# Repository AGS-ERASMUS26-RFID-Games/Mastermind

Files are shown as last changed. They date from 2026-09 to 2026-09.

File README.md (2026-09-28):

# RFID Games – Documentation

Arduino Mega 2560 project with two games, *Mastermind* and the
*Color Memory Game*, on the same hardware: four RFID readers, a 16×16 LED
matrix and three buttons.

This file describes the game selection, both game principles, the settings,
the display, the structure of the code and the wiring (section 7). Both
games are in one sketch, `rfid_games.ino`. The complete schematic is
`mastermind.kicad_sch` (KiCad 7); it did not change for the second game.

---

## 1. Game selection

| Button | Pin | Function |
|---|---|---|
| Button 1 | D2 | start a game, confirm an input |
| Button 2 | D3 | select **Mastermind**; hold 3 s = quit the running game |
| Button 3 | D18 | select **Color Memory Game**; hold 3 s = quit the running game |

- After switching on, **Mastermind** is selected and its start screen appears.
- Button 2 and button 3 work on every **start screen** and every **end
  screen** (win, lose, game over). They show the start screen of the
  selected game. Button 1 then starts it.
- During a **running game**, a short press of button 2 or button 3 is
  ignored, so an accidental press never ends a game. The press is discarded
  and does not act later either.
- **Quitting a running game:** hold button 2 or button 3 for 3 s
  (`ABORT_HOLD_TIME`). The game ends immediately and the start screen of
  the selected game appears – button 2 → Mastermind, button 3 → Color
  Memory Game. There is no progress display; after 3 s the start screen
  simply appears. Releasing earlier cancels the hold, the game continues.
  This works in every phase of a running game, also while the Color Memory
  sequence is shown.
- A button that is already held down when a game starts does not quit the
  new game; it has to be released and pressed again first. The same
  applies after quitting: the button still held does not count twice.
- On an end screen, button 1 starts a new game of the **same** game
  directly.

---

## 2. Mastermind

At the start of a game, the Arduino rolls a secret sequence of four colors.
The choices are **Red, Green, Blue and Yellow**; each color may appear more
than once. The player tries to guess this sequence.

### Course of a round

1. **Input:** A color chip is placed on each of the four readers. The
   corresponding LED in the current row shows the color of the chip. If no
   chip (or an unknown chip) is present, the LED lights up white.
2. **Confirm:** As soon as a known chip lies on all four readers, the row
   **blinks**. Pressing button 1 confirms the input. With the chip lock
   active, all readers are checked once more first; if the result differs
   from the display, the press is ignored and the corrected row is shown
   (see "Chip lock").
3. **Evaluate:** To the right of the input, the result appears as four LEDs:
   - **Green** = right color in the right position
   - **Yellow** = right color, but in the wrong position
   - **Red** = no hit for this chip: its color does not appear in the
     sequence, or all chips of this color in the sequence are already
     matched by other hits (see the duplicate rule below)

   The evaluation is **not position-based**: all green LEDs light up first,
   then all yellow ones, then the red ones. So the order does *not*
   reveal which position is correct – exactly like real Mastermind.
4. **Continue:** The next attempt is entered in the row below.

### Winning and losing

- **Won:** All four evaluation LEDs are green (color *and* position correct
  everywhere).
- **Lost:** The maximum number of attempts (`MM_MAX_ATTEMPTS`) is reached
  without the sequence being guessed.

In both cases a final screen appears (see section 5), after which a new game
starts at the press of button 1.

### Evaluation – an example

Secret sequence: **Red · Red · Green · Blue**

| Input | Green | Yellow | Red | Explanation |
|---|---|---|---|---|
| Red · Green · Green · Blue | 3 | 0 | 1 | Positions 1, 3, 4 match; the second green is one too many |
| Red · Blue · Blue · Red | 1 | 1 | 2 | Position 1 matches (green); another Red exists in the sequence but is misplaced (yellow) |
| Yellow · Yellow · Yellow · Yellow | 0 | 0 | 4 | Yellow does not appear in the sequence at all |

Important is the rule for duplicate colors: Each chip of the secret sequence
can produce only **one** hit. A second Red in the input only turns yellow if
the secret sequence also contains a second (not yet matched) Red.

---

## 3. Color Memory Game

The player has to remember a random color sequence and rebuild it with the
chips. The sequence gets one color longer with every successful round.

### Course of a round

1. **New sequence:** At the beginning of every round the Arduino generates a
   **completely new** random sequence of the colors Red, Green, Blue and
   Yellow. The previous sequence is not extended. Round 1 has 1 color,
   round 2 has 2 colors, and so on up to `CM_MAX_LENGTH` (20). After that,
   every round has 20 colors – the game continues endlessly until a mistake
   is made.
2. **Display:** After a short dark pause, the **whole sequence is shown at
   once** on a grid (see section 5). The display time grows with the
   length: `CM_SHOW_TIME_BASE` + `CM_SHOW_TIME_PER_COLOR` per color
   (default 1.5 s for 1 color, 11 s for 20 colors). Then every used grid
   place turns white: the player sees how many colors are needed, but no
   longer which ones.
3. **Input in blocks:** Because there are only four readers, the sequence is
   entered in blocks of four – one block per grid row. Reader 1 to 4
   correspond to position 1 to 4 of the current row. The last block only
   needs as many readers as colors are left (e.g. 2 readers for a sequence
   of 6). The readers that are not needed are **not read at all** and can
   never get a chip (see "Active readers" in section 4). A chip placed on
   them is ignored.
   - The current row shows the chips live, exactly as in Mastermind (no /
     unknown chip → white).
   - When a known chip lies on every required reader, the row **blinks** and
     button 1 confirms the block. With the chip lock active, the readers are
     checked once more first (see "Chip lock").
   - The confirmed block stays visible on the grid in its colors.
4. **Remove the chips:** Before the next block can be confirmed, the chips
   have to be removed from the required readers. As long as chips of the
   last block are still lying there, the next row stays **white** (it does
   not show the chip colors and does not blink), and button 1 is ignored.
   Only when all required readers were empty does the row show the chips
   live again. This also applies to the first block of a round: chips still
   lying there from the previous round are not shown. This makes it possible to use the same
   chips several times in one sequence (e.g. Red – Blue – Red – Red – Red)
   and prevents a double press from confirming the same block twice.
5. **Evaluate:** Only when the complete sequence has been entered does the
   Arduino compare it with the generated sequence, **position by
   position**. Directly below every color an LED appears:
   - **Green** = correct color at this position → **1 point**
   - **Red** = wrong color at this position
6. **Continue:** If every position is correct, the next round starts with a
   new sequence that is one color longer. If at least one position is
   wrong, the game is over.

### Evaluation – an example

Generated sequence: **Red · Blue · Yellow · Green**

| Position | Sequence | Input | Result |
|---|---|---|---|
| 1 | Red | Red | Green LED, +1 point |
| 2 | Blue | Blue | Green LED, +1 point |
| 3 | Yellow | Green | Red LED |
| 4 | Green | Green | Green LED, +1 point |

Position 3 is wrong, so the game ends after this evaluation.

### Scoring

The score is the number of correct positions **over all rounds of a game**.
Correct positions of the last, failed round count as well.

Example: rounds 1 to 3 without a mistake, then 2 of 4 positions correct in
round 4 → score = 1 + 2 + 3 + 2 = **8**.

### Game over

The end screen alternates between the scrolling text “GAME OVER” in red and
the score as a green number (section 5). Button 1 starts a new game in
round 1 with score 0; button 2 or 3 switches the game.

---

## 4. Operation and important constants

All settings are grouped together at the top of the sketch under *Settings*
and *Pins*: first the Mastermind settings (prefix `MM_`), then the Color
Memory Game settings (prefix `CM_`), then the settings both games share.

### Mastermind

| Constant | Default | Meaning |
|---|---|---|
| `MM_DEBUG_SHOW_SOLUTION` | `true` (test setting) | `true` = show the secret sequence in row 16 during the game (for testing). Set to `false` for normal play. |
| `MM_MAX_ATTEMPTS` | `1` (test setting) | Number of attempts, after which the game is lost. Allowed are **1–15** (row 16 is reserved for the debug solution). An invalid value produces a clear error message at compile time. Use e.g. `10` for normal play. |

### Color Memory Game

| Constant | Default | Meaning |
|---|---|---|
| `CM_MAX_LENGTH` | `20` | Maximum length of the sequence. Allowed are **1–20** (the grid has 5 rows × 4 positions), checked at compile time. After reaching it, every round has this length. |
| `CM_SHOW_PAUSE` | `300` ms | Dark pause before the sequence appears |
| `CM_SHOW_TIME_BASE` | `1000` ms | Display time of the sequence … |
| `CM_SHOW_TIME_PER_COLOR` | `500` ms | … plus this much per color |

### Shared

| Constant | Default | Meaning |
|---|---|---|
| `DEBUG` | `1` | `1` = serial output on (UIDs, solution, evaluation), `0` = off (saves a little memory) |
| `BRIGHTNESS` | `4` | Brightness of the matrix (0–255) |
| `BLINK_INTERVAL` | `250` ms | Blink rate of a complete input |
| `SCROLL_INTERVAL` | `70` ms | Speed of the scrolling texts (smaller = faster) |
| `END_IMAGE_DURATION` | `4000` ms | Dwell time of the end image before the scrolling text runs again |
| `RESULT_PAUSE` | `1500` ms | Leave the last evaluation on screen before the next screen (end screen resp. next round) appears |
| `DEBOUNCE_TIME` | `30` ms | Debounce of the buttons |
| `ABORT_HOLD_TIME` | `3000` ms | Hold button 2 / 3 this long to quit a running game |

The RFID timing values (`MAX_FAILED_READS`, `POLL_INTERVAL`,
`ANTENNA_WAIT`) come from the original reader sketch and are unchanged. If
chips are detected unreliably, increase `ANTENNA_WAIT` first.

### Range of the readers: gain and transmitter power

The four readers lie only about **3 mm** apart. In addition, some readers
do not lie completely flat, because the pins on their back lift them up on
one side. A tilted reader has a different distance to the chip than its
neighbors, and its field reaches further to one side. Both make it easy for
a chip to be detected by a neighboring reader as well.

If a chip is also detected by a neighboring reader, the range of the
readers can be reduced with two settings. Because the modules differ, both
are set **individually for every reader**: each constant is an array with
one entry per reader (reader 1 first).

| Constant | Default | Meaning |
|---|---|---|
| `RFID_GAIN_STEP[]` | `{ 2, 2, 1, 1 }` | Receiver gain per reader, step `0`–`5` |
| `TX_POWER_STEP[]` | `{ 2, 1, 1, 2 }` | Transmitter power per reader, step `1`–`8` |
| `PROBE_GAIN_STEP` | `2` | Gain of all readers during the power test of the chip lock (see [Chip lock](#chip-lock)) |
| `FALLBACK_MIN_GAIN_STEP` | `0` | Lowest gain step for a repeated read after a read error (see [Read errors](#read-errors-reading-again-with-less-gain)) |

All values are checked at compile time: an entry outside its allowed range
stops the compilation with an error message.

`RFID_GAIN_STEP` sets the receiver gain, i.e. how well the reader "hears"
the answer of a chip. The RC522 only knows these six values, there are no
steps in between:

| Step | 0 | 1 | 2 | 3 | 4 | 5 |
|---|---|---|---|---|---|---|
| Gain | 18 dB | 23 dB | 33 dB (library default) | 38 dB | 43 dB | 48 dB |

`TX_POWER_STEP` sets the transmitter power, i.e. the strength of the field
itself. A weaker field means a chip on a neighboring reader is no longer
powered at all, which usually works better than a lower gain. Step 8 is the
library default (full power). The MFRC522 library has no function for this;
the sketch writes the driver conductance registers directly: `CWGsPReg` =
step × 4 and the upper half of `GsNReg` = step (step 8 → `0x20` / `0x8` =
reset values). The field does not drop linearly: neighboring steps may
hardly differ, and below a certain step detection stops abruptly.

How far the range actually drops depends on the module, its antenna and
how flat it lies, so the right combination has to be found by testing. The
default values were determined with the separate test sketch
`rfid_sweep_test.ino` (block "RECOMMENDED SETTINGS" in its output). Repeat
this test after changing the hardware – a module swapped, readers moved,
other chips – and enter the recommended values in `RFID_GAIN_STEP` and
`TX_POWER_STEP`.

For fine-tuning, all values can also be changed at runtime via the Serial
Monitor (`DEBUG 1`, 9600 baud), without uploading the sketch again. This
works in every state of both games. A command consists of the letter, the
reader (`0` = all readers, `1`–`4` = one reader) and the step:

| Input | Effect | Example |
|---|---|---|
| `g<reader><step>` | set gain step `0`–`5` | `g24` = reader 2 → 43 dB, `g01` = all readers → 23 dB |
| `t<reader><step>` | set transmitter power step `1`–`8` | `t38` = reader 3 → step 8, `t02` = all readers → step 2 |
| `?` | show current settings | |

After every change the settings of all readers are printed, together with
the values read back from each reader (gain `0x00`/`0x10`/`0x40`/…,
`CWGsP` = step × 4, `GsN` with the step in the upper digit), the gain used
for the power test and finally the current values in the form of the
constants, e.g.

```
RFID settings:
  Reader 1: gain step 2 (33 dB), TX step 2  | gain 0x40 | CWGsP 0x8 | GsN 0x28
  ...
  Power test: gain step 2 (33 dB) on all readers, TX steps 1..8
  constexpr byte RFID_GAIN_STEP[READER_COUNT] = { 2, 2, 1, 1 };
  constexpr byte TX_POWER_STEP[READER_COUNT]  = { 2, 1, 1, 2 };
```

If a reader shows different register values than expected, it did not
accept the setting. Recommended procedure: for each setting, first check
that chips lying directly on each reader are still detected, then check
that a chip on one reader no longer appears on its neighbors. Copy the two
last lines of the output into the sketch – changes made via serial are lost
after a restart.

### Read errors: reading again with less gain

A typical problem with readers this close together: the own chip lies on
the reader, and at the same time a chip on the neighboring reader answers
weakly. With high gain the reader hears both answers, they overlap and the
answer can no longer be decoded. Without a countermeasure the reader would
report *no* chip – the own chip would disappear as long as the neighbor
chip lies there.

`readReader()` therefore distinguishes between "no chip answers" (timeout,
normal) and "a chip answers, but the answer is garbled" (read error). After
a read error, the reader immediately reads again with less gain, one step
at a time down to `FALLBACK_MIN_GAIN_STEP` (default `0` = 18 dB), until the
read is clean. The weak neighbor chip drops below the receiver threshold
first, while the own chip directly on the antenna is still read. Afterwards
the normal gain of the reader is restored. If no step reads cleanly, the
read with the most chips is used.

With `DEBUG 1` a line is printed only when the state of a reader changes,
e.g. `Reader 2: read error at 33 dB -> clean read at 23 dB`,
`Reader 2: read error, also with less gain` or
`Reader 2: reads normally again`. If a reader frequently needs the fallback,
its normal gain is probably too high.

### Active readers

Only the readers the running game needs at the moment are read. In
Mastermind these are always all four. In the Color Memory Game they are only
the readers of the current block: in round 1 only reader 1, for a sequence
of 6 first readers 1–4, then readers 1–2. `activeReaderCount()` returns this
number; `pollReaders()` skips all readers above it.

An inactive reader therefore can never get a chip, neither by its own read
nor by the chip lock. This matters because an empty reader is exactly the
one that picks up the chip of its neighbor most easily. Example: the last
block has 2 colors, and the chip on reader 2 is also seen by reader 3.
Reader 3 is not read at all, so the chip only appears at reader 2 and
belongs to it immediately – no power test, no tie, no white LED.

If an inactive reader still shows a chip from the previous block, it is
forgotten as soon as the reader becomes inactive. A side effect of skipping
the inactive readers: a round with fewer readers is faster.

One limit remains: if a chip is placed on an unused reader while its
active neighbor is **empty**, the neighbor may pick it up and show its
color, because the unused reader cannot claim the chip any more. Chips on
unused readers should therefore simply be avoided.

### Chip lock

If gain and transmitter power alone do not prevent cross-reading, the chip
lock (`CHIP_LOCK = true`, default) makes sure that every chip is assigned
to exactly one reader. It is used by both games. Each polling round then
runs in three steps:

1. **Read:** every active reader reads *all* chips in its field (up to
   `MAX_CHIPS_PER_READER`, default 3), not just one. This matters because
   with two chips in the field the RC522 selects one by its UID bits, not by
   distance – a reader could otherwise report the neighbor's chip instead of
   its own. The reader wakes all chips (WUPA), reads one, puts it to sleep
   (HALT) and then asks again with REQA, which sleeping chips ignore, until
   no chip answers any more.
2. **Assign:** every chip is assigned to at most one reader, by these rules:
   - *Elimination:* if only one free reader is left for a chip, the chip
     belongs to it and the reader is taken. Example: reader 1 sees A and B,
     reader 2 only B → A can only belong to reader 1, so B belongs to
     reader 2. This solves the common case without any measurement.
   - A chip whose readers are all taken belongs to nobody (it was only
     cross-read).
   - *Power test:* if a chip is still seen by several free readers, the
     transmitter power of each of them is lowered step by step (binary
     search over steps 1–8, 4 reads per reader). The reader that still sees
     the chip at the lowest step is closest and gets it. Because the normal
     settings differ from reader to reader, the power test does **not** use
     them: every reader is measured with the same gain `PROBE_GAIN_STEP`
     (default `2` = 33 dB) over the same range 1–8, so the results of
     different readers can be compared. Afterwards each reader gets its
     normal gain and transmitter power back. The result is remembered for
     `PROBE_CACHE_TIME` (default 3000 ms) as long as the same readers
     compete, so the test does not run in every round.
   - If several chips can only belong to the same reader, it keeps the chip
     it already shows; otherwise the power test decides here as well.
   - *Tie:* if several readers reach the same lowest step, the reader that
     already shows this chip keeps it, so a tie does not make a displayed
     chip vanish. The same applies if several chips on one reader tie: the
     chip the reader already shows stays.
   - *In case of doubt white:* if none of the tied readers shows the chip
     yet, nobody gets it. The affected reader shows white, the row does not
     blink and cannot be confirmed – the player sees the problem and
     straightens the chip.

   The reader that currently shows a chip stays a candidate for it even if
   it missed it in this round, so a single dropout does not hand the chip
   over to a neighbor.
3. **Update:** if a chip now belongs to a different reader than before, it
   is removed from the old reader at once. Otherwise the usual rules apply
   (new chip / swap immediately, removal after `MAX_FAILED_READS` failed
   reads).

Before a press of button 1 is accepted – a Mastermind attempt as well as a
Color Memory block – one more complete round runs with a fresh power test
(no remembered results). Only if nothing changes is the input accepted. A
wrong color can therefore never be confirmed.

With `DEBUG 1` every power test is printed, e.g.
`Chip 04 99 32 BB seen by readers 1+2 -> power test: R1=4 R2=1 -> reader 2`
(the number is the lowest step at which the reader still saw the chip,
`-` = not at all). A tie that is resolved in favor of the current reader
appears as `-> tie, reader 1 keeps it`, an undecided one as
`-> undecided, nobody`. This also shows how clearly the readers can be
told apart: if the numbers are far apart, the readers are well separated;
if they are often equal, try a different `PROBE_GAIN_STEP`. Since the
power test always uses its own settings, changing `RFID_GAIN_STEP` /
`TX_POWER_STEP` does not change these numbers.

**Cost:** a reader with a chip needs one extra request per round (about
25 ms timeout), so a round with all four readers occupied takes roughly
100 ms longer. A power test takes a few hundred milliseconds, during which
blinking may stutter briefly. The repeated reads after a read error (see
above) only cost time when an error actually occurs – at most one extra
read per gain step below the normal one. `CHIP_LOCK = false` restores the old
behavior (every reader shows the first chip it sees) for comparison.

### First-time setup: filling the chip table

The 16 chips are entered in the `CHIPS[]` table – each UID plus a color index
(1 = Red, 2 = Green, 3 = Blue, 4 = Yellow). Both games use the same table.
To determine a chip's UID, leave `DEBUG` at `1`, open the Serial Monitor
(9600 baud), start a game and place the chip on a reader. Write the printed
hex UID into the matching slot in the table. At startup, `checkTable()`
automatically checks for empty slots, duplicate UIDs, wrong color
distribution and invalid color indices, and reports anomalies via serial.

---

## 5. Display on the matrix

The matrix is 16×16 pixels. Rows and positions are counted **from 1** in the
code (`setLED(row, position, color)`).

All texts on the matrix are in English, and the serial debug output is in
English as well.

### Mastermind

```
        Position →   3  4  5  6      10 11 12 13
Row 1                [ Input    ]    [ Feedback ]   ← Attempt 1
Row 2                [ Input    ]    [ Feedback ]   ← Attempt 2
  ...
Row 10               [ Input    ]    [ Feedback ]   ← Attempt 10
  ...
Row 16                               [ Solution ]   ← only with MM_DEBUG_SHOW_SOLUTION
```

- **Input** (columns 3–6): the four readers from left to right.
- **Feedback** (columns 10–13): green/yellow/red, see section 2.
- **Row 16** shows the secret sequence when `MM_DEBUG_SHOW_SOLUTION` is
  active.

### Color Memory Game

The sequence is placed on a grid of 5 rows × 4 positions. Sequence position
*n* (counted from 0 in the code) lies in grid row *n* / 4 at grid position
*n* % 4. Every grid row is one input block; its feedback lies directly
below it.

```
          Position →    2     6        11    15
Row 1
Row 2   Block 1         [1]   [2]      [3]   [4]     ← colors 1–4
Row 3                   [ feedback for colors 1–4 ]
Row 4
Row 5   Block 2         [5]   [6]      [7]   [8]
Row 6                   [ feedback for colors 5–8 ]
  ...
Row 14  Block 5         [17]  [18]     [19]  [20]
Row 15                  [ feedback for colors 17–20 ]
Row 16
```

- **Colors** (rows 2, 5, 8, 11, 14): during the display the sequence, then
  white placeholders. During the input the current row shows the chips
  live (white until the chips of the previous block were removed);
  confirmed blocks show the entered colors.
- **Feedback** (rows 3, 6, 9, 12, 15): green = correct, red = wrong, only
  after the complete sequence has been entered.
- The arrangement is set in `CM_GRID_POSITION[]`, `CM_INPUT_ROW[]` and
  `CM_FEEDBACK_ROW[]`.

### Orientation of the matrix

On our matrix the first LED (pixel 0) sits **top right**, the first row runs
from right to left, and each further row alternates direction (zigzag). In the
code this is set via `NEO_MATRIX_TOP + NEO_MATRIX_RIGHT + NEO_MATRIX_ROWS +
NEO_MATRIX_ZIGZAG`. The library uses this to convert the coordinates itself,
so that position 1 is on the left and row 1 at the top, and text scrolls
through the right way round. If the matrix is ever installed differently, only
this line needs to be adjusted.

### Start and end screens

- **Start screens:** colorful scrolling text “MASTERMIND - PRESS BUTTON”
  resp. “COLOR MEMORY GAME - PRESS BUTTON”.

All end screens alternate between a scrolling text and a still image until a
button is pressed:

| End screen | Scrolling text | Still image |
|---|---|---|
| Mastermind won | “YOU WIN!” in green | solution as four 2×2 color blocks, below it the **number of attempts** as a green number |
| Mastermind lost | “YOU LOSE” in red | solution as four 2×2 color blocks, below it a **red X** |
| Color Memory game over | “GAME OVER” in red | the **score** as a green number |

Numbers with 1–2 digits are drawn in the default font, bold. Numbers with
3–4 digits (a Color Memory score from 100 upwards) do not fit in this font
and are drawn in the small 3×5 font `TomThumb` (part of the Adafruit GFX
library). Values above 9999 are shown as 9999.

---

## 6. Structure of the code

The sketch is organized as a **state machine**. There is always exactly one
active state, and `loop()` calls the matching function depending on the
state:

```
  Mastermind                               Color Memory Game

  S_MM_START                               S_CM_START
      │ Button 1                               │ Button 1
      ▼                                        ▼
  S_MM_GAME ─ all green ──────► S_MM_WON   S_CM_SHOW ◄────────────────────────┐
      ▲  │                         │           │ display time over            │ all correct
      │  └─ MM_MAX_ATTEMPTS ► S_MM_LOST        ▼                              │ (next round)
      │                            │       S_CM_INPUT ── sequence entered ────┤
      └──────── Button 1 ◄─────────┘                                          │ error
                                                                              ▼
                                           S_CM_SHOW ◄── Button 1 ──── S_CM_GAME_OVER
                                           (new game, round 1)

  From every start and end screen:  Button 2 → S_MM_START,  Button 3 → S_CM_START
  From every running game state:    hold button 2 / 3 for 3 s → S_MM_START / S_CM_START
```

| State | Constant | Function in `loop()` |
|---|---|---|
| Mastermind start screen | `S_MM_START` | `loopStart()` |
| Mastermind running game | `S_MM_GAME` | `mmLoopGame()` |
| Mastermind win screen | `S_MM_WON` | `loopEnd()` |
| Mastermind lose screen | `S_MM_LOST` | `loopEnd()` |
| Color Memory start screen | `S_CM_START` | `loopStart()` |
| Color Memory sequence display | `S_CM_SHOW` | `cmLoopShow()` |
| Color Memory input | `S_CM_INPUT` | `cmLoopInput()` |
| Color Memory game over screen | `S_CM_GAME_OVER` | `loopEnd()` |

### Naming conventions

- Everything that belongs to only **one game** has a prefix: `mm` / `MM_`
  for Mastermind (e.g. `mmNewGame()`, `mmSecretCode`, `MM_MAX_ATTEMPTS`),
  `cm` / `CM_` for the Color Memory Game (e.g. `cmNewGame()`,
  `cmSequence`, `CM_MAX_LENGTH`). State constants: `S_MM_…`, `S_CM_…`;
  texts: `TEXT_MM_…`, `TEXT_CM_…`.
- Everything that **both games share** has no prefix: buttons, RFID, chip
  lock, matrix helpers, blinking, start/end screens.
- Constants in `UPPER_CASE`, variables and functions in `camelCase`, rows
  and positions on the matrix counted from 1.

### Sections of the sketch

The sketch is one file, in this order: *Settings*, *Pins*, *RFID timing*,
*Layout*, *Colors*, *Texts*, *Chip-color table*, *Objects*, *State*, then
the functions: *Buttons*, *LED matrix*, *RFID*, *Chip lock*, *Shared game
helpers*, *Mastermind*, *Color Memory Game*, *Screens*, *States*,
*Setup/Loop*.

### The most important functions

**Flow / states**

- `setup()` – initializes the matrix, the three button interrupts and the
  four readers (first all `PCD_Init()` calls, then `applyRfidSettings()` and
  antenna-off, so no later init resets these settings), and shows the
  Mastermind start screen.
- `loop()` – dispatches to the loop functions depending on `state`.
- `loopStart()` – shows the colorful start scrolling text of the selected
  game; button 1 calls `mmNewGame()` resp. `cmNewGame()`, button 2 / 3
  switch the game.
- `mmLoopGame()` – polls the readers, updates the display, lets the row
  blink and reacts to button 1.
- `cmLoopShow()` – dark pause, then shows the sequence for
  `cmShowDuration()`, then calls `cmStartInput()`. Non-blocking.
- `cmLoopInput()` – polls the readers, releases the next block once its
  readers are empty, lets the row blink and reacts to button 1.
- `loopEnd()` – alternates between the final scrolling text and the end
  image of the current end screen; button 1 starts a new game of the same
  game, button 2 / 3 switch the game.

**Game selection / screens**

- `selectGame()` – on start and end screens: button 2 → `S_MM_START`,
  button 3 → `S_CM_START`.
- `ignoreSelectButtons()` – in the running game: discards short presses of
  button 2 / 3.
- `checkAbort()` – called at the beginning of every running game state
  (`mmLoopGame()`, `cmLoopShow()`, `cmLoopInput()`). Calls
  `ignoreSelectButtons()` and quits the game if button 2 / 3 is held for
  `ABORT_HOLD_TIME`.
- `startStartScreen(startState)` / `startEndScreen(endState)` – enter a
  start resp. end screen and discard old button presses.
- `drawEndImage()` – calls `mmDrawEndImage()` or `cmDrawEndImage()`.

**Shared game helpers**

- `activeReaderCount()` – number of readers the running game needs at the
  moment (Mastermind 4, Color Memory the size of the current block). Only
  readers 1 to this number are read.
- `inputConfirmable()` / `drawInputRow()` – pass the work on to the game
  that is running (`mm…` or `cm…` function of the same name).
- `blinkTick()` – advances the blinking of a confirmable input row. Also
  called during the RFID polling so the blinking stays even.
- `restartBlink()` – starts the blinking visible and redraws the row (after
  every change).

**Mastermind**

- `mmNewGame()` – generates the secret sequence and resets everything.
- `mmConfirmAttempt()` – checks whether confirmation is allowed, evaluates
  the attempt, draws the result, increments `mmAttemptCount` and decides
  between win/lose/continue.
- `mmEvaluate(attempt, green, yellow)` – the actual Mastermind evaluation
  (green = color + position, yellow = color only). Handles duplicate colors
  correctly via two count fields.
- `mmInputComplete()` / `mmInputConfirmable()` – check whether all four
  readers are occupied resp. whether the input is also different from the
  last attempt. Only then does the row blink and button 1 get accepted.
- `mmDrawInputRow()`, `mmDrawFeedback(row, green, yellow)`,
  `mmDrawEndImage()` – display.

**Color Memory Game**

- `cmNewGame()` – resets length and score, calls `cmNextRound()`.
- `cmNextRound()` – makes the sequence one color longer (up to
  `CM_MAX_LENGTH`), generates it completely new and starts `S_CM_SHOW`.
- `cmStartInput()` – turns the grid places white and starts `S_CM_INPUT`.
- `cmBlockSize()` – number of readers needed for the current block (4, or
  fewer for the last block). This is also the number of active readers
  during the input.
- `cmInputComplete()` / `cmInputConfirmable()` – check whether all required
  readers carry a known chip resp. whether additionally the chips of the
  last block were removed (`cmWaitForEmpty`).
- `cmBlockReadersEmpty()` – are the required readers free of chips?
- `cmConfirmBlock()` – stores the block in `cmInput[]` (without evaluating
  it) and calls `cmEvaluate()` once the sequence is complete.
- `cmEvaluate()` – compares position by position, draws green/red below
  the colors, adds the points and decides between next round and game
  over.
- `cmSetGridLED(index, color)` / `cmSetFeedbackLED(index, color)` – set the
  LED of a sequence position resp. the feedback below it.
- `cmDrawInputRow()`, `cmDrawEndImage()` – display. `cmDrawInputRow()`
  draws the current row white as long as `cmWaitForEmpty` is set.

**RFID**

- `readAllChips(reader, uids, error)` – polls a single reader and reads all
  chips in its field (with `CHIP_LOCK = false` only the first). Only the
  antenna of the reader currently being polled is ever active; this
  prevents mutual interference and relieves the 3.3 V regulator. `error`
  is set if a chip answered but the answer could not be decoded (no answer
  at all is not an error).
- `readReader(i, uids)` – reads reader `i` via `readAllChips()` and repairs
  read errors by reading again with less gain (down to
  `FALLBACK_MIN_GAIN_STEP`). Used by `pollReaders()`.
- `noteFallback(i, state)` – (only with `DEBUG 1`) prints a line when the
  read-error state of a reader changes.
- `setTxPower(i, step)` – sets the transmitter power of one reader.
- `findColor(uid)` – looks up the UID in the chip table and returns the color
  index (unknown → 0 = White).
- `applyReaderSettings(i)` – writes the gain and transmitter power of
  reader `i` (`gainStep[i]` / `txStep[i]`).
- `applyRfidSettings()` – writes the settings of all four readers.
- `reportRfidSettings()` – prints the settings of every reader, the
  registers read back and the values in the form of the constants
  (`printStepArray()`).
- `serialTuning()` – (only with `DEBUG 1`) reads the commands
  `g<reader><step>`, `t<reader><step>` and `?` from the Serial Monitor.
- `pollReaders(fresh)` – one complete round: read all active readers,
  assign the chips, update the display state. Inactive readers are skipped
  and forget their chip. Returns `true` if a displayed color has
  changed. `fresh = true` ignores remembered power-test results (used
  before confirming).
- `updateReader(i, uid)` – encapsulates new detection, chip swap and the
  failed-read counter against dropouts for one reader.

**Chip lock**

- `resolveOwners(owner, fresh)` – assigns every chip seen in the round to
  at most one reader (elimination, then power test).
- `decideContested(uid, mask, fresh)` – power test for a chip seen by
  several readers, with the remembered results (`probeCache`). On a tie
  the reader that already shows the chip keeps it.
- `decideOnReader(...)` – several chips that can only belong to the same
  reader: keep the current one, otherwise power test (on a tie, too, the
  current chip stays).
- `probeThreshold(i, uid)` – lowest transmitter power step at which reader
  `i` still sees the chip (binary search over 1–8 with `PROBE_GAIN_STEP`),
  then restores the normal settings of the reader.

**Display**

- `setLED(row, position, color)` – sets one LED (coordinates from 1).
- `scrollTextStep(text, color)` – draws **one** step of a scrolling text
  (non-blocking) and reports when the text has run through completely.
- `drawNumber(value, y, color)` – draws a centered number (1–2 digits bold,
  3–4 digits in the small font). Used by both end images.

**Buttons**

- `handleButtonEdge(b)` – shared logic of the interrupt routines. Detects a
  real press via edge + debounce and remembers the moment (`micros()`).
- `buttonConfirmISR()`, `buttonMastermindISR()`, `buttonColorMemoryISR()` –
  one interrupt routine per button (an ISR cannot take parameters); each
  only calls `handleButtonEdge()`.
- `fetchButton(b)` – hands a pending press of button `b` to the main
  program and resets the flag; also used to discard old presses.
- `discardButtons()` – discards the presses of all buttons.
- `buttonHeld(b)` – is button `b` still down, for at least
  `ABORT_HOLD_TIME` since its last press? The press time
  (`buttonPressMillis[]`) is stored by the interrupt; whether the button is
  still down is read directly from the pin. A release and a new press start
  a new hold, because the interrupt then stores a new press time.
- `cancelHolds()` – buttons held at this moment no longer count as held
  (`buttonHoldUsed[]`) until they are pressed again. Called when a game
  starts and after quitting.

### Why interrupts for the buttons?

When no chip is present, each reader waits for a timeout. A full polling round
can therefore take more than 100 ms – with the chip lock and all readers
occupied about 250–300 ms, during a power test even longer. A short click that
falls exactly within that time would be missed with a simple `digitalRead()`.
All three button pins are interrupt-capable, so every press is captured via an
interrupt and buffered safely – no button press is lost, guaranteed.

Holding a button does not need an extra interrupt: the interrupt already
stores the moment of the press, and `buttonHeld()` only reads the pin in
the main program. The debounce keeps the bouncing on release from counting
as a new press. A long polling round only delays the quitting by a moment;
the hold itself is measured from the press.

On the Mega the interrupt-capable pins are D2, D3, D18, D19, D20 and D21.
`attachInterrupt(digitalPinToInterrupt(pin), …)` translates the pin number
into the right interrupt number itself, so nothing has to be changed in the
code if a button is moved to another of these pins – only its entry in
`BUTTON_PINS[]`. The Arduino interrupt number and the interrupt of the
ATmega2560 itself are not the same:

| Button | Pin | Arduino interrupt | ATmega2560 interrupt |
|---|---|---|---|
| Button 1 | D2 | 0 | INT4 |
| Button 2 | D3 | 1 | INT5 |
| Button 3 | D18 | 5 | INT3 |

### Why is the Color Memory display a separate state?

With 20 colors the sequence stays on screen for 11 s. Instead of waiting
with `delay()`, `cmLoopShow()` measures the time with `millis()` – like the
end screens. `loop()` therefore keeps running: the Serial Monitor tuning
still works during the display, and button presses are buffered and then
deliberately discarded when the input starts. The short pauses after an
evaluation (`RESULT_PAUSE`) still use `delay()`, as before in Mastermind.

### Randomness and memory

- **Randomness:** The moment of the button press that starts a game
  (`micros()`) serves as the seed for the random number generator. This is
  practically unpredictable, so the sequences reliably differ from game to
  game.
- **Memory:** The Mega has 8 KB of RAM (the UNO only 2 KB), of which the
  matrix occupies 768 bytes. The chip table (`CHIPS[]`) and all texts still
  live in flash (`PROGMEM`) instead of in RAM. On the Mega this is no longer
  strictly necessary, but it costs nothing and leaves RAM free for later
  extensions. Already-played Mastermind attempts are not stored separately
  – they are on the matrix anyway. The
  Color Memory Game needs two arrays of `CM_MAX_LENGTH` bytes (sequence and
  input), because the input is only evaluated at the end.

### Memory usage (Arduino Mega 2560 / ATmega2560)

Measured with Arduino AVR core 1.8.6 and avr-gcc 7.3.0:

| Variant | Flash (of 248 KB) | RAM (incl. 768-byte matrix buffer at runtime) |
|---|---|---|
| `DEBUG 1` | 28 418 bytes ≈ 11 % | 1 679 bytes ≈ 20 % |
| `DEBUG 0` | 23 414 bytes ≈ 9 % | 1 626 bytes ≈ 20 % |

The RAM figure reported by the Arduino IDE is lower (911 resp. 858 bytes)
because it does not yet include the matrix buffer – that is only allocated
at runtime. Depending on the compiler version of the IDE, the flash values
can differ by a few hundred bytes (the Mastermind-only sketch measured
23 232 bytes with this compiler, 23 780 bytes in the IDE). With more than
6 KB of free RAM there is plenty of room for the stack and for extensions
(e.g. more readers, sound).

The chip lock alone needs about 3 KB of flash and about 100 bytes of RAM.
For comparison, the Mastermind-only sketch (`mastermind.ino`, measured in
the IDE):

| Variant | Flash (of 248 KB) | RAM (incl. 768-byte matrix buffer at runtime) |
|---|---|---|
| `DEBUG 1` | 23 780 bytes ≈ 9 % | 1 568 bytes ≈ 19 % |
| `DEBUG 0` | 20 530 bytes ≈ 8 % | 1 513 bytes ≈ 18 % |

Compared with the same compiler (`DEBUG 1`: 26 986 vs. 23 232 bytes before
the per-reader settings), the Color Memory Game and the game selection add
about 3.7 KB of flash and about 100 bytes of RAM. The per-reader gain and
transmitter power, the repeated read after read errors and the tie rule of
the power test add about 1.5 KB of flash with `DEBUG 1` (most of it serial
output) resp. 0.7 KB with `DEBUG 0`, and 10–14 bytes of RAM.

---

## 7. Wiring (Arduino Mega 2560)

The complete schematic is in `mastermind.kicad_sch`. In the sketch, the pins
are defined at the top under *Pins*.

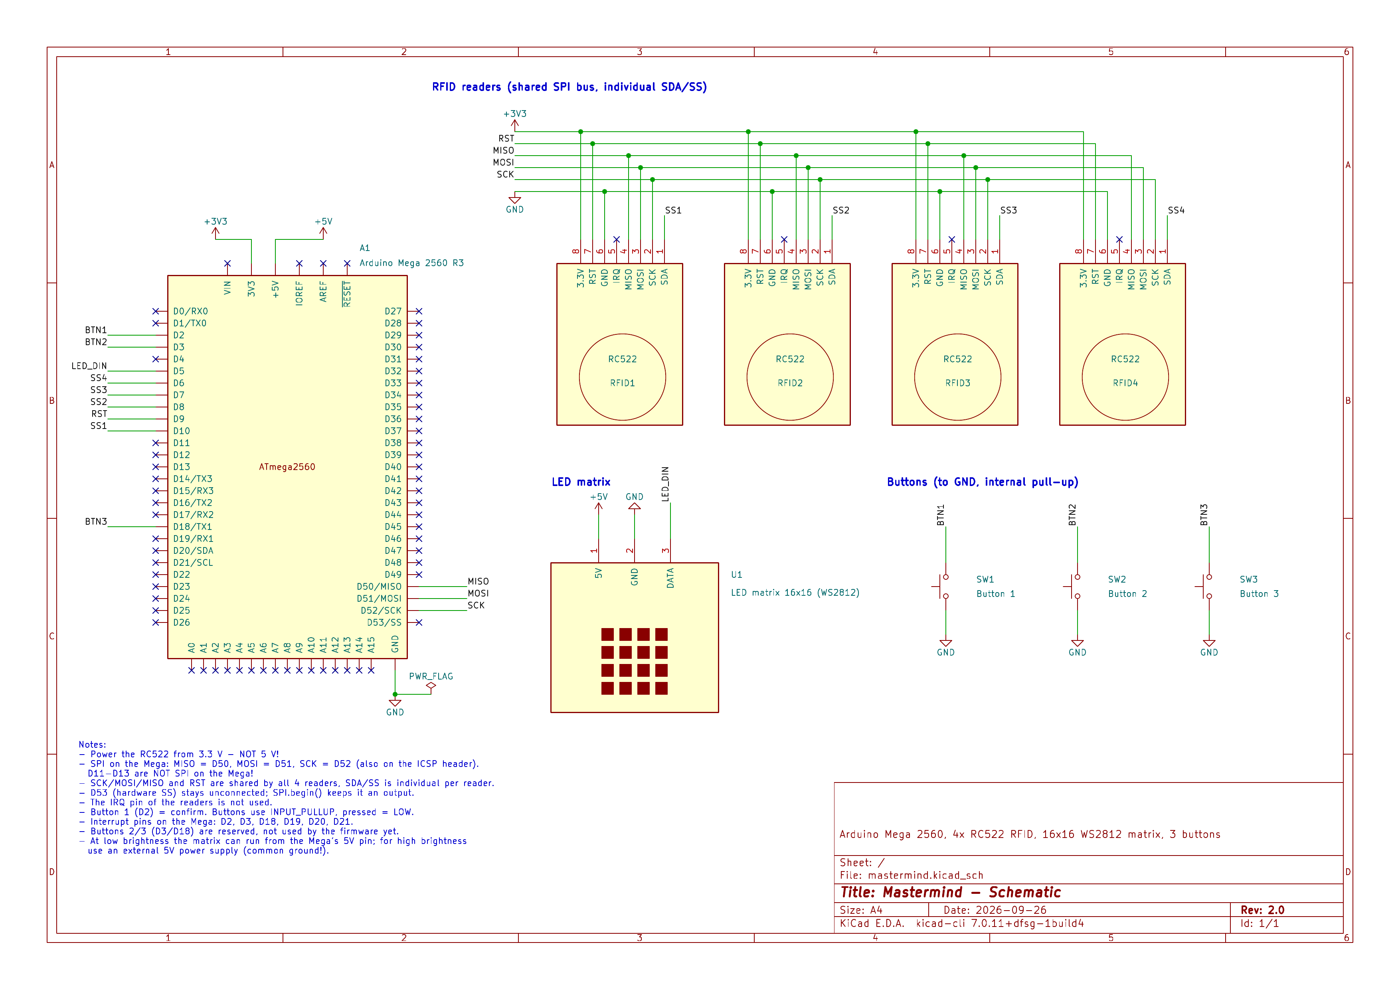
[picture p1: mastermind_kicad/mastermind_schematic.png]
Schematic – Arduino Mega 2560 version


### Pin assignment

| Mega pin | Signal | Connected to | Note |
|---|---|---|---|
| D2 | `BTN1` | Button 1 (start / confirm) → GND | interrupt pin, `INPUT_PULLUP`, pressed = LOW |
| D3 | `BTN2` | Button 2 (select Mastermind) → GND | interrupt pin, `INPUT_PULLUP`, pressed = LOW |
| D5 | `LED_DIN` | LED matrix DATA/DIN | |
| D6 | `SS4` | Reader 4 SDA | |
| D7 | `SS3` | Reader 3 SDA | |
| D8 | `SS2` | Reader 2 SDA | |
| D9 | `RST` | RST of all 4 readers | shared |
| D10 | `SS1` | Reader 1 SDA | |
| D18 | `BTN3` | Button 3 (select Color Memory Game) → GND | interrupt pin, `INPUT_PULLUP`, pressed = LOW; TX1, free as long as `Serial1` is not used |
| D50 | `MISO` | MISO of all 4 readers | hardware SPI, shared |
| D51 | `MOSI` | MOSI of all 4 readers | hardware SPI, shared |
| D52 | `SCK` | SCK of all 4 readers | hardware SPI, shared |
| D53 | – | not connected | hardware SS, stays an output (`SPI.begin()`) |
| 3.3V | `+3V3` | 3.3V of all 4 readers | **not 5 V!** |
| 5V | `+5V` | LED matrix 5V | see "Power supply" |
| GND | `GND` | readers, matrix, buttons | common ground |
| D0 / D1 | – | not connected | USB serial (Serial Monitor) |

The IRQ pins of the readers are not used.

### Changes compared to the UNO wiring

- **SPI moves:** on the Mega the hardware SPI is on D50 (MISO), D51 (MOSI)
  and D52 (SCK) – *not* on D11/D12/D13 as on the UNO. The same three signals
  are also available on the 6-pin ICSP header. If the readers stay connected
  to D11–D13, they are not detected (firmware version `0x00` or `0xFF` in the
  Serial Monitor).
- **Button 3 moves** from D4 to D18, so all three buttons are on
  interrupt-capable pins (on the Mega: D2, D3, D18, D19, D20, D21).
- All other signals (SS1–SS4, RST, LED_DIN, button 1 and 2) keep their pin
  numbers.
- In the Arduino IDE select **Tools → Board → "Arduino Mega or Mega 2560"**
  (processor ATmega2560). If another board is selected, the sketch stops at
  compile time with `Wrong board selected` on purpose.

### Power supply

- The RC522 readers run on **3.3 V only**. The Mega's 3.3 V pin (onboard
  regulator, approx. 150 mA) is enough because only one reader antenna is
  switched on at any time.
- At low brightness (`BRIGHTNESS = 4`) the matrix can run from the Mega's
  5 V pin. For higher brightness use an external 5 V power supply for the
  matrix and connect its ground to the Mega's GND (common ground!). With a
  20-color sequence the Color Memory Game lights at most about 40 LEDs at
  once, fewer than a scrolling text.

### Libraries

MFRC522 (miguelbalboa), Adafruit GFX, Adafruit NeoMatrix and Adafruit
NeoPixel – all available in the Arduino Library Manager. The small font
`Fonts/TomThumb.h` is part of Adafruit GFX.

---

## 8. Changes compared to the separate sketches

For everyone who knows `mastermind.ino` or `Color-Memory-Game.ino`:

**Mastermind**

- The game logic is unchanged. Game-specific names got the prefix `mm` /
  `MM_` (e.g. `newGame()` → `mmNewGame()`, `MAX_ATTEMPTS` →
  `MM_MAX_ATTEMPTS`, `S_GAME` → `S_MM_GAME`).
- `fetchButton()` now takes the button number (`fetchButton(BUTTON_CONFIRM)`).
- The blinking (`blinkTick()`, `drawInputRow()`) is shared with the Color
  Memory Game; the repeated "blink on, redraw" lines are now
  `restartBlink()`.
- Drawing the number of attempts moved to `drawNumber()`.
- The end-image comment and this documentation now say 2×2 blocks – which
  is what the code always drew (the old documentation said 3×3).

**Both games**

- Button 2 (D3) and button 3 (D18) were only reserved in the Mastermind
  wiring and not used by the firmware. They now select the game and quit a
  running game. The wiring itself did not change.
- A running game can be quit by holding button 2 or 3 for 3 s (new; before
  there was no way out of a running game except a reset).

**Color Memory Game**

- Runs on the Mega wiring and uses the Mastermind RFID code including the
  chip lock instead of its own `readChip()` / `checkReader()`. Names follow
  the Mastermind conventions (e.g. `NUMBER_OF_READERS` → `READER_COUNT`,
  `getButtonPress()` → `fetchButton()`, `memorySequence` → `cmSequence`).
- Blocks are fixed to the readers (reader 1–4 = position 1–4); gaps are no
  longer skipped. A block must be complete (4 chips, the last block only the
  remaining ones) before it blinks and can be confirmed.
- Only the readers of the current block are read (`activeReaderCount()`).
  Unused readers can no longer take over the chip of a neighbor through
  cross-reading.
- The chips have to be removed between two blocks (was described in the game
  principle, but not checked in the code).
- The display time grows with the length (was fixed at 1.1 s).
- The sequence display is a non-blocking state (`S_CM_SHOW`); the unused
  `STATE_DISPLAY` is gone.
- Confirmed blocks stay visible; the feedback appears together with the
  entered colors.
- The feedback now lies **directly** below its row (rows 3, 6, 9, 12, 15).
  In the old code it was one row further down, next to the following input
  row, although the comment said "directly below".
- The score is displayed in the bold style of Mastermind resp. the small
  font from 100 upwards (a 3-digit number was cut off before), and for
  `END_IMAGE_DURATION` (4 s instead of 3 s).
- After round 20 the game continues endlessly with 20 colors (unchanged).

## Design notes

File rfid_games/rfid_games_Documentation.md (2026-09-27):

# RFID Games – Documentation

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

---

## 1. Game selection

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

---

## 2. Mastermind

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

### Course of a round

1. **Input:** A color chip is placed on each of the four readers. The
   corresponding LED in the current row shows the color of the chip. If no
   chip (or an unknown chip) is present, the LED lights up white.
2. **Confirm:** As soon as a known chip lies on all four readers, the row
   **blinks**. Pressing button 1 confirms the input. With the chip lock
   active, all readers are checked once more first; if the result differs
   from the display, the press is ignored and the corrected row is shown
   (see "Chip lock").
3. **Evaluate:** To the right of the input, the result appears as four LEDs:
   - **Green** = right color in the right position
   - **Yellow** = right color, but in the wrong position
   - **Off** = no hit for this color

   The evaluation is **not position-based**: all green LEDs light up first,
   then all yellow ones. So the order does *not* reveal which position is
   correct – exactly like real Mastermind.
4. **Continue:** The next attempt is entered in the row below.

### Winning and losing

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

### Evaluation – an example

Secret sequence: **Red · Red · Green · Blue**

| Input | Green | Yellow | Explanation |
|---|---|---|---|
| Red · Green · Green · Blue | 3 | 0 | Positions 1, 3, 4 match; the second green is one too many |
| Red · Blue · Blue · Red | 1 | 1 | Position 1 matches (green); another Red exists in the sequence but is misplaced (yellow) |
| Yellow · Yellow · Yellow · Yellow | 0 | 0 | Yellow does not appear in the sequence at all |

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

---

## 3. Color Memory Game

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

### Course of a round

1. **New sequence:** At the beginning of every round the Arduino generates a
   **completely new** random sequence of the colors Red, Green, Blue and
   Yellow. The previous sequence is not extended. Round 1 has 1 color,
   round 2 has 2 colors, and so on up to `CM_MAX_LENGTH` (20). After that,
   every round has 20 colors – the game continues endlessly until a mistake
   is made.
2. **Display:** After a short dark pause, the **whole sequence is shown at
   once** on a grid (see section 5). The display time grows with the
   length: `CM_SHOW_TIME_BASE` + `CM_SHOW_TIME_PER_COLOR` per color
   (default 1.5 s for 1 color, 11 s for 20 colors). Then every used grid
   place turns white: the player sees how many colors are needed, but no
   longer which ones.
3. **Input in blocks:** Because there are only four readers, the sequence is
   entered in blocks of four – one block per grid row. Reader 1 to 4
   correspond to position 1 to 4 of the current row. The last block only
   needs as many readers as colors are left (e.g. 2 readers for a sequence
   of 6). The readers that are not needed are **not read at all** and can
   never get a chip (see "Active readers" in section 4). A chip placed on
   them is ignored.
   - The current row shows the chips live, exactly as in Mastermind (no /
     unknown chip → white).
   - When a known chip lies on every required reader, the row **blinks** and
     button 1 confirms the block. With the chip lock active, the readers are
     checked once more first (see "Chip lock").
   - The confirmed block stays visible on the grid in its colors.
4. **Remove the chips:** Before the next block can be confirmed, the chips
   have to be removed from the required readers. As long as chips of the
   last block are still lying there, the next row shows them but does not
   blink, and button 1 is ignored. This makes it possible to use the same
   chips several times in one sequence (e.g. Red – Blue – Red – Red – Red)
   and prevents a double press from confirming the same block twice.
5. **Evaluate:** Only when the complete sequence has been entered does the
   Arduino compare it with the generated sequence, **position by
   position**. Directly below every color an LED appears:
   - **Green** = correct color at this position → **1 point**
   - **Red** = wrong color at this position
6. **Continue:** If every position is correct, the next round starts with a
   new sequence that is one color longer. If at least one position is
   wrong, the game is over.

### Evaluation – an example

Generated sequence: **Red · Blue · Yellow · Green**

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

Position 3 is wrong, so the game ends after this evaluation.

### Scoring

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

### Game over

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

---

## 4. Operation and important constants

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

### Mastermind

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

### Color Memory Game

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

### Shared

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

### Range of the readers: gain and transmitter power

If a chip is also detected by a neighboring reader, the range of the
readers can be reduced with two settings. Both are applied to all four
readers.

`RFID_GAIN_STEP` (default `2`) sets the receiver gain, i.e. how well the
reader "hears" the answer of a chip. The RC522 only knows these six values,
there are no steps in between:

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

`TX_POWER_STEP` (default `4`, allowed `1`–`8`) sets the transmitter power,
i.e. the strength of the field itself. A weaker field means a chip on a
neighboring reader is no longer powered at all, which usually works better
than a lower gain. Step 8 is the library default (full power). The MFRC522
library has no function for this; the sketch writes the driver conductance
registers directly: `CWGsPReg` = step × 4 and the upper half of `GsNReg` =
step (step 8 → `0x20` / `0x8` = reset values). The field does not drop
linearly: neighboring steps may hardly differ, and below a certain step
detection stops abruptly.

How far the range actually drops depends on the module and its antenna, so
the right combination has to be found by testing. For this, both values
can be changed at runtime via the Serial Monitor (`DEBUG 1`, 9600 baud),
without uploading the sketch again. This works in every state of both
games:

| Input | Effect |
|---|---|
| `g0` … `g5` | set gain step |
| `t1` … `t8` | set transmitter power step |
| `?` | show current settings |

After every change the values read back from each reader are printed
(gain `0x00`/`0x10`/`0x40`/…, `CWGsP` = step × 4, `GsN` with the step in the
upper digit). If a reader shows different values, it did not accept the
setting. Recommended procedure: for each setting, first check that chips
lying directly on each reader are still detected, then check that a chip on
one reader no longer appears on its neighbor. Enter the combination found
in `RFID_GAIN_STEP` and `TX_POWER_STEP` – changes made via serial are lost
after a restart.

### Active readers

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

### Chip lock

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

1. **Read:** every active reader reads *all* chips in its field (up to
   `MAX_CHIPS_PER_READER`, default 3), not just one. This matters because
   with two chips in the field the RC522 selects one by its UID bits, not by
   distance – a reader could otherwise report the neighbor's chip instead of
   its own. The reader wakes all chips (WUPA), reads one, puts it to sleep
   (HALT) and then asks again with REQA, which sleeping chips ignore, until
   no chip answers any more.
2. **Assign:** every chip is assigned to at most one reader, by these rules:
   - *Elimination:* if only one free reader is left for a chip, the chip
     belongs to it and the reader is taken. Example: reader 1 sees A and B,
     reader 2 only B → A can only belong to reader 1, so B belongs to
     reader 2. This solves the common case without any measurement.
   - A chip whose readers are all taken belongs to nobody (it was only
     cross-read).
   - *Power test:* if a chip is still seen by several free readers, the
     transmitter power of each of them is lowered step by step (binary
     search, 3–4 reads per reader). The reader that still sees the chip at
     the lowest step is closest and gets it. The result is remembered for
     `PROBE_CACHE_TIME` (default 3000 ms) as long as the same readers
     compete, so the test does not run in every round.
   - If several chips can only belong to the same reader, it keeps the chip
     it already shows; otherwise the power test decides here as well.
   - *In case of doubt white:* on a tie nobody gets the chip. The affected
     reader shows white, the row does not blink and cannot be confirmed –
     the player sees the problem and straightens the chip.

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

With `DEBUG 1` every power test is printed, e.g.
`Chip 04 99 32 BB seen by readers 1+2 -> power test: R1=4 R2=1 -> reader 2`
(the number is the lowest step at which the reader still saw the chip,
`-` = not at all). This also shows how clearly the readers can be told
apart: if the numbers are far apart, the setting is good; if they are
often equal, lower the transmitter power a little further.

**Cost:** a reader with a chip needs one extra request per round (about
25 ms timeout), so a round with all four readers occupied takes roughly
100 ms longer. A power test takes a few hundred milliseconds, during which
blinking may stutter briefly. `CHIP_LOCK = false` restores the old
behavior (every reader shows the first chip it sees) for comparison.

### First-time setup: filling the chip table

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

---

## 5. Display on the matrix

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

### Mastermind

```
        Position →   3  4  5  6      10 11 12 13
Row 1                [ Input    ]    [ Feedback ]   ← Attempt 1
Row 2                [ Input    ]    [ Feedback ]   ← Attempt 2
  ...
Row 10               [ Input    ]    [ Feedback ]   ← Attempt 10
  ...
Row 16                               [ Solution ]   ← only with MM_DEBUG_SHOW_SOLUTION
```

- **Input** (columns 3–6): the four readers from left to right.
- **Feedback** (columns 10–13): green/yellow/off, see section 2.
- **Row 16** shows the secret sequence when `MM_DEBUG_SHOW_SOLUTION` is
  active.

### Color Memory Game

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

```
          Position →    2     6        11    15
Row 1
Row 2   Block 1         [1]   [2]      [3]   [4]     ← colors 1–4
Row 3                   [ feedback for colors 1–4 ]
Row 4
Row 5   Block 2         [5]   [6]      [7]   [8]
Row 6                   [ feedback for colors 5–8 ]
  ...
Row 14  Block 5         [17]  [18]     [19]  [20]
Row 15                  [ feedback for colors 17–20 ]
Row 16
```

- **Colors** (rows 2, 5, 8, 11, 14): during the display the sequence, then
  white placeholders. During the input the current row shows the chips
  live; confirmed blocks show the entered colors.
- **Feedback** (rows 3, 6, 9, 12, 15): green = correct, red = wrong, only
  after the complete sequence has been entered.
- The arrangement is set in `CM_GRID_POSITION[]`, `CM_INPUT_ROW[]` and
  `CM_FEEDBACK_ROW[]`.

### Orientation of the matrix

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

### Start and end screens

- **Start screens:** colorful scrolling text “MASTERMIND - PRESS BUTTON”
  resp. “COLOR MEMORY GAME - PRESS BUTTON”.

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

---

## 6. Structure of the code

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

```
  Mastermind                               Color Memory Game

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

  From every start and end screen:  Button 2 → S_MM_START,  Button 3 → S_CM_START
  From every running game state:    hold button 2 / 3 for 3 s → S_MM_START / S_CM_START
```

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

### Naming conventions

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

### Sections of the sketch

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

### The most important functions

**Flow / states**

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

**Game selection / screens**

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

**Shared game helpers**

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

**Mastermind**

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

**Color Memory Game**

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

**RFID**

- `readAllChips(reader, uids)` – polls a single reader and reads all chips
  in its field (with `CHIP_LOCK = false` only the first). Only the antenna
  of the reader currently being polled is ever active; this prevents mutual
  interference and relieves the 3.3 V regulator.
- `setTxPower(i, step)` – sets the transmitter power of one reader.
- `findColor(uid)` – looks up the UID in the chip table and returns the color
  index (unknown → 0 = White).
- `applyRfidSettings()` – writes the current gain and transmitter power
  step to all four readers.
- `serialTuning()` – (only with `DEBUG 1`) reads the commands `g0`–`g5`,
  `t1`–`t8` and `?` from the Serial Monitor.
- `pollReaders(fresh)` – one complete round: read all active readers,
  assign the chips, update the display state. Inactive readers are skipped
  and forget their chip. Returns `true` if a displayed color has
  changed. `fresh = true` ignores remembered power-test results (used
  before confirming).
- `updateReader(i, uid)` – encapsulates new detection, chip swap and the
  failed-read counter against dropouts for one reader.

**Chip lock**

- `resolveOwners(owner, fresh)` – assigns every chip seen in the round to
  at most one reader (elimination, then power test).
- `decideContested(uid, mask, fresh)` – power test for a chip seen by
  several readers, with the remembered results (`probeCache`).
- `decideOnReader(...)` – several chips that can only belong to the same
  reader: keep the current one, otherwise power test.
- `probeThreshold(i, uid)` – lowest transmitter power step at which reader
  `i` still sees the chip (binary search).

**Display**

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

**Buttons**

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

### Why interrupts for the buttons?

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

### Why is the Color Memory display a separate state?

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

### Randomness and memory

- **Randomness:** The moment of the button press that starts a game
  (`micros()`) serves as the seed for the random number generator. This is
  practically unpredictable, so the sequences reliably differ from game to
  game.
- **Memory:** The Mega has 8 KB of RAM (the UNO only 2 KB), of which the
  matrix occupies 768 bytes. The chip table (`CHIPS[]`) and all texts still
  live in flash (`PROGMEM`) instead of in RAM. Already-played Mastermind
  attempts are not stored separately – they are on the matrix anyway. The
  Color Memory Game needs two arrays of `CM_MAX_LENGTH` bytes (sequence and
  input), because the input is only evaluated at the end.

### Memory usage (Arduino Mega 2560 / ATmega2560)

Measured with Arduino AVR core 1.8.6 and avr-gcc 7.3.0:

| Variant | Flash (of 248 KB) | RAM (incl. 768-byte matrix buffer at runtime) |
|---|---|---|
| `DEBUG 1` | 26 986 bytes ≈ 10 % | 1 669 bytes ≈ 20 % |
| `DEBUG 0` | 22 762 bytes ≈ 9 % | 1 612 bytes ≈ 20 % |

The RAM figure reported by the Arduino IDE is lower (901 resp. 844 bytes)
because it does not yet include the matrix buffer – that is only allocated
at runtime. Depending on the compiler version of the IDE, the flash values
can differ by a few hundred bytes (the Mastermind-only sketch measured
23 232 bytes with this compiler, 23 780 bytes in the IDE). With more than
6 KB of free RAM there is plenty of room for the stack and for extensions.

---

## 7. Wiring (Arduino Mega 2560)

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

Schematic – Arduino Mega 2560 version

### Pin assignment

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

The IRQ pins of the readers are not used.

### Changes compared to the UNO wiring

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

### Power supply

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

### Libraries

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

---

## 8. Changes compared to the separate sketches

For everyone who knows `mastermind.ino` or `Color-Memory-Game.ino`:

**Mastermind**

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

**Both games**

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

**Color Memory Game**

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

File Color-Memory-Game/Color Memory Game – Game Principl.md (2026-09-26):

# Color Memory Game – Game Principle

## 1. Objective of the Game

The **Color Memory Game** is a memory game based on RFID technology and an LED matrix.

The player has to remember a randomly generated sequence of colors. The colors are displayed using a 16×16 LED matrix. The player then has to reproduce the sequence by placing RFID chips with the corresponding colors on four RFID readers.

The sequence becomes longer with every successful round.

---

## 2. Starting the Game

When the Arduino is switched on, the game displays a start screen.

The LED matrix shows the message:

**"COLOR MEMORY GAME - PRESS BUTTON"**

The player starts the game by pressing the button.

After the button is pressed, the first round begins.

---

## 3. Generating the Memory Sequence

At the beginning of every round, the Arduino generates a **completely new random sequence**.

The sequence consists of four possible colors:

* Red
* Green
* Blue
* Yellow

The length of the sequence depends on the current round.

For example:

* Round 1 → 1 color
* Round 2 → 2 colors
* Round 3 → 3 colors
* Round 4 → 4 colors
* Round 5 → 5 colors
* Round 6 → 6 colors
* etc.

The maximum sequence length is **20 colors**.

The sequence is newly generated for every round. The previous sequence is therefore **not extended**.

---

## 4. Displaying the Sequence

After generating the sequence, the LED matrix displays all colors of the sequence.

The colors are displayed **simultaneously** so that the player can memorize their positions.

For example, a sequence could look like:

**Red – Blue – Yellow – Green**

The player has to memorize this sequence before entering it.

The display remains visible for a certain amount of time before the input phase begins.

---

## 5. Entering the Sequence

After the sequence has been displayed, the player has to reproduce it using the RFID chips.

There are four RFID readers.

Each reader can detect one RFID chip at a time.

The player places the colored chips on the readers to enter the sequence.

For example:

**Red → Blue → Yellow → Green**

The system detects the color of every chip by reading its RFID UID.

The UID is assigned to a specific color in the program.

---

## 6. Entering More Than Four Colors

Because there are only four RFID readers, the player can enter a maximum of four colors at the same time.

However, the memory sequence can contain more than four colors.

For example, if the sequence has eight colors:

**Red – Blue – Green – Yellow – Yellow – Red – Blue – Green**

the player enters the sequence in two blocks:

**Block 1:**
Red – Blue – Green – Yellow

**Block 2:**
Yellow – Red – Blue – Green

The player can therefore enter sequences of up to 20 colors even though there are only four RFID readers.

---

## 7. Reusing the Same RFID Chips

The same RFID chip can be used multiple times in one sequence.

For example:

**Red – Blue – Red – Yellow – Red**

is a valid sequence.

The player must remove the chips from the readers before using the same chips again.

This allows the same color to appear multiple times in a sequence.

---

## 8. Evaluating the Input

The entered sequence is **not evaluated after every four colors**.

Instead, all input blocks are stored first.

Only when the complete sequence has been entered does the Arduino compare the player's input with the generated sequence.

This is important for longer sequences because the player can enter the complete sequence without immediately receiving feedback after every block.

---

## 9. Correct and Incorrect Colors

The Arduino compares the player's sequence with the generated sequence **position by position**.

For every position, there are two possible results:

### Correct

If the entered color is exactly the same as the generated color at the same position, the position is correct.

The LED matrix displays this position in **green**.

The player receives **one point** for every correct position.

### Incorrect

If the entered color does not match the generated color at the same position, the position is incorrect.

The LED matrix displays this position in **red**.

An incorrect position causes the game to end.

---

## 10. Example of an Evaluation

Generated sequence:

**Red – Blue – Yellow – Green**

Player input:

**Red – Blue – Green – Green**

The result is:

| Position | Correct Sequence | Player Input | Result |
| --- | --- | --- | --- |
| 1 | Red | Red | 🟢 Correct |
| 2 | Blue | Blue | 🟢 Correct |
| 3 | Yellow | Green | 🔴 Incorrect |
| 4 | Green | Green | 🟢 Correct |

The LED matrix therefore displays green for the correct positions and red for the incorrect position.

Because one position is incorrect, the game ends.

---

## 11. Scoring

The player receives **one point for every correctly entered position**.

For example:

**Sequence length: 8**

**Correct positions: 7**

**Score: 7 points**

The score is displayed after the evaluation.

---

## 12. Successful Round

If the entire sequence is correct, the player successfully completes the round.

The game then starts the next round.

The next sequence contains **one additional color**.

For example:

**Round 3 → 3 colors**

After successfully completing it:

**Round 4 → 4 colors**

The difficulty therefore increases with every successful round.

---

## 13. Game Over

If at least one color is entered incorrectly, the game ends.

The LED matrix displays:

**"GAME OVER"**

as a scrolling message.

Afterwards, the player's score is displayed.

The player can then press the button to start a new game.

---

## 14. New Game

When a new game is started:

* The score is reset to 0.
* The sequence length is reset to 1.
* A completely new random sequence is generated.
* The player starts again at Round 1.

The previous game's sequence is not reused.

---

## 15. Complete Game Flow

The complete game process can be summarized as follows:

**Start Screen**
↓
**Press Button**
↓
**Generate Random Sequence**
↓
**Display Sequence**
↓
**Player Enters Sequence**
↓
**Store Input Blocks**
↓
**Complete Sequence Entered**
↓
**Compare Input with Generated Sequence**
↓
**Correct?**

### Yes:

**Display Green Feedback**
↓
**Add Points**
↓
**Next Round**
↓
**Generate New, Longer Sequence**

### No:

**Display Red Feedback**
↓
**Game Over**
↓
**Display Score**
↓
**Press Button**
↓
**New Game**

---

## 16. Purpose of the Game

The main purpose of the Color Memory Game is to combine **memory training with RFID and LED technology**.

The project demonstrates several technical concepts:

* RFID communication
* Reading RFID UIDs
* Assigning RFID tags to colors
* Using multiple RFID readers
* Controlling an LED matrix
* Generating random sequences
* Storing user input
* Comparing arrays and sequences
* Managing different program states
* Creating an interactive game using Arduino

The increasing sequence length makes the game progressively more challenging and tests the player's ability to remember and reproduce longer color sequences.

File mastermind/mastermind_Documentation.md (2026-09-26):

# Mastermind – Documentation

Arduino Mega 2560 version of the game *Mastermind* with four RFID readers,
a 16×16 LED matrix and a confirmation button.

This file describes the wiring (section 5), the game principle and the
structure of the code. The complete schematic is `mastermind.kicad_sch`
(KiCad 7).

---

## 1. Game principle

At the start of a game, the Arduino rolls a secret sequence of four colors.
The choices are **Red, Green, Blue and Yellow**; each color may appear more
than once. The player tries to guess this sequence.

### Course of a round

1. **Input:** A color chip is placed on each of the four readers. The
   corresponding LED in the current row shows the color of the chip. If no
   chip (or an unknown chip) is present, the LED lights up white.
2. **Confirm:** As soon as a known chip lies on all four readers, the row
   **blinks**. Pressing the button confirms the input. With the chip lock
   active, all readers are checked once more first; if the result differs
   from the display, the press is ignored and the corrected row is shown
   (see "Chip lock").
3. **Evaluate:** To the right of the input, the result appears as four LEDs:
   - **Green** = right color in the right position
   - **Yellow** = right color, but in the wrong position
   - **Off** = no hit for this color

   The evaluation is **not position-based**: all green LEDs light up first,
   then all yellow ones. So the order does *not* reveal which position is
   correct – exactly like real Mastermind.
4. **Continue:** The next attempt is entered in the row below.

### Winning and losing

- **Won:** All four evaluation LEDs are green (color *and* position correct
  everywhere).
- **Lost:** The maximum number of attempts (`MAX_ATTEMPTS`) is reached
  without the sequence being guessed.

In both cases a final screen appears (see section 3), after which a new game
starts at the press of the button.

### Evaluation – an example

Secret sequence: **Red · Red · Green · Blue**

| Input | Green | Yellow | Explanation |
|---|---|---|---|
| Red · Green · Green · Blue | 3 | 0 | Positions 1, 3, 4 match; the second green is one too many |
| Red · Blue · Blue · Red | 1 | 1 | Position 1 matches (green); another Red exists in the sequence but is misplaced (yellow) |
| Yellow · Yellow · Yellow · Yellow | 0 | 0 | Yellow does not appear in the sequence at all |

Important is the rule for duplicate colors: Each chip of the secret sequence
can produce only **one** hit. A second Red in the input only turns yellow if
the secret sequence also contains a second (not yet matched) Red.

---

## 2. Operation and important constants

All settings are grouped together at the top of the sketch under *Settings*
and *Pins*.

| Constant | Default | Meaning |
|---|---|---|
| `DEBUG` | `1` | `1` = serial output on (UIDs, solution, evaluation), `0` = off (saves a little memory) |
| `DEBUG_SHOW_SOLUTION` | `true` (test setting) | `true` = show the secret sequence in row 16 during the game (for testing). Set to `false` for normal play. |
| `MAX_ATTEMPTS` | `1` (test setting) | Number of attempts, after which the game is lost. Allowed are **1–15** (row 16 is reserved for the debug solution). An invalid value produces a clear error message at compile time. Use e.g. `10` for normal play. |
| `BRIGHTNESS` | `4` | Brightness of the matrix (0–255) |
| `BLINK_INTERVAL` | `250` ms | Blink rate of the complete input |
| `SCROLL_INTERVAL` | `70` ms | Speed of the scrolling texts (smaller = faster) |
| `END_IMAGE_DURATION` | `4000` ms | Dwell time of the solution image before the scrolling text runs again |
| `RESULT_PAUSE` | `1500` ms | Leave the last evaluation on screen before the end screen appears |
| `DEBOUNCE_TIME` | `30` ms | Debounce of the button |

The RFID timing values (`MAX_FAILED_READS`, `POLL_INTERVAL`,
`ANTENNA_WAIT`) come from the original reader sketch and are unchanged. If
chips are detected unreliably, increase `ANTENNA_WAIT` first.

### Range of the readers: gain and transmitter power

If a chip is also detected by a neighboring reader, the range of the
readers can be reduced with two settings. Both are applied to all four
readers.

`RFID_GAIN_STEP` (default `2`) sets the receiver gain, i.e. how well the
reader "hears" the answer of a chip. The RC522 only knows these six values,
there are no steps in between:

| Step | 0 | 1 | 2 | 3 | 4 | 5 |
|---|---|---|---|---|---|---|
| Gain | 18 dB | 23 dB | 33 dB (library default) | 38 dB | 43 dB | 48 dB |

`TX_POWER_STEP` (default `4`, allowed `1`–`8`) sets the transmitter power,
i.e. the strength of the field itself. A weaker field means a chip on a
neighboring reader is no longer powered at all, which usually works better
than a lower gain. Step 8 is the library default (full power). The MFRC522
library has no function for this; the sketch writes the driver conductance
registers directly: `CWGsPReg` = step × 4 and the upper half of `GsNReg` =
step (step 8 → `0x20` / `0x8` = reset values). The field does not drop
linearly: neighboring steps may hardly differ, and below a certain step
detection stops abruptly.

How far the range actually drops depends on the module and its antenna, so
the right combination has to be found by testing. For this, both values
can be changed at runtime via the Serial Monitor (`DEBUG 1`, 9600 baud),
without uploading the sketch again:

| Input | Effect |
|---|---|
| `g0` … `g5` | set gain step |
| `t1` … `t8` | set transmitter power step |
| `?` | show current settings |

After every change the values read back from each reader are printed
(gain `0x00`/`0x10`/`0x40`/…, `CWGsP` = step × 4, `GsN` with the step in the
upper digit). If a reader shows different values, it did not accept the
setting. Recommended procedure: for each setting, first check that chips
lying directly on each reader are still detected, then check that a chip on
one reader no longer appears on its neighbor. Enter the combination found
in `RFID_GAIN_STEP` and `TX_POWER_STEP` – changes made via serial are lost
after a restart.

### Chip lock

If gain and transmitter power alone do not prevent cross-reading, the chip
lock (`CHIP_LOCK = true`, default) makes sure that every chip is assigned
to exactly one reader. Each polling round then runs in three steps:

1. **Read:** every reader reads *all* chips in its field (up to
   `MAX_CHIPS_PER_READER`, default 3), not just one. This matters because
   with two chips in the field the RC522 selects one by its UID bits, not by
   distance – a reader could otherwise report the neighbor's chip instead of
   its own. The reader wakes all chips (WUPA), reads one, puts it to sleep
   (HALT) and then asks again with REQA, which sleeping chips ignore, until
   no chip answers any more.
2. **Assign:** every chip is assigned to at most one reader, by these rules:
   - *Elimination:* if only one free reader is left for a chip, the chip
     belongs to it and the reader is taken. Example: reader 1 sees A and B,
     reader 2 only B → A can only belong to reader 1, so B belongs to
     reader 2. This solves the common case without any measurement.
   - A chip whose readers are all taken belongs to nobody (it was only
     cross-read).
   - *Power test:* if a chip is still seen by several free readers, the
     transmitter power of each of them is lowered step by step (binary
     search, 3–4 reads per reader). The reader that still sees the chip at
     the lowest step is closest and gets it. The result is remembered for
     `PROBE_CACHE_TIME` (default 3000 ms) as long as the same readers
     compete, so the test does not run in every round.
   - If several chips can only belong to the same reader, it keeps the chip
     it already shows; otherwise the power test decides here as well.
   - *In case of doubt white:* on a tie nobody gets the chip. The affected
     reader shows white, the row does not blink and cannot be confirmed –
     the player sees the problem and straightens the chip.

   The reader that currently shows a chip stays a candidate for it even if
   it missed it in this round, so a single dropout does not hand the chip
   over to a neighbor.
3. **Update:** if a chip now belongs to a different reader than before, it
   is removed from the old reader at once. Otherwise the usual rules apply
   (new chip / swap immediately, removal after `MAX_FAILED_READS` failed
   reads).

Before a button press is accepted, one more complete round runs with a
fresh power test (no remembered results). Only if nothing changes is the
attempt evaluated. A wrong color can therefore never be confirmed.

With `DEBUG 1` every power test is printed, e.g.
`Chip 04 99 32 BB seen by readers 1+2 -> power test: R1=4 R2=1 -> reader 2`
(the number is the lowest step at which the reader still saw the chip,
`-` = not at all). This also shows how clearly the readers can be told
apart: if the numbers are far apart, the setting is good; if they are
often equal, lower the transmitter power a little further.

**Cost:** a reader with a chip needs one extra request per round (about
25 ms timeout), so a round with all four readers occupied takes roughly
100 ms longer. A power test takes a few hundred milliseconds, during which
blinking may stutter briefly. `CHIP_LOCK = false` restores the old
behavior (every reader shows the first chip it sees) for comparison.

### First-time setup: filling the chip table

The 16 chips are entered in the `CHIPS[]` table – each UID plus a color index
(1 = Red, 2 = Green, 3 = Blue, 4 = Yellow). To determine a chip's UID, leave
`DEBUG` at `1`, open the Serial Monitor (9600 baud) and place the chip on a
reader. Write the printed hex UID into the matching slot in the table. At
startup, `checkTable()` automatically checks for empty slots, duplicate UIDs,
wrong color distribution and invalid color indices, and reports anomalies via
serial.

---

## 3. Display on the matrix

The matrix is 16×16 pixels. Rows and positions are counted **from 1** in the
code (`setLED(row, position, color)`).

```
        Position →   3  4  5  6      10 11 12 13
Row 1                [ Input    ]    [ Feedback ]   ← Attempt 1
Row 2                [ Input    ]    [ Feedback ]   ← Attempt 2
  ...
Row 10               [ Input    ]    [ Feedback ]   ← Attempt 10
  ...
Row 16                               [ Solution ]   ← only with DEBUG_SHOW_SOLUTION
```

- **Input** (columns 3–6): the four readers from left to right.
- **Feedback** (columns 10–13): green/yellow/off, see above.
- **Row 16** shows the secret sequence when `DEBUG_SHOW_SOLUTION` is active.

All texts on the matrix are in English, and the serial debug output is in
English as well.

### Orientation of the matrix

On our matrix the first LED (pixel 0) sits **top right**, the first row runs
from right to left, and each further row alternates direction (zigzag). In the
code this is set via `NEO_MATRIX_TOP + NEO_MATRIX_RIGHT + NEO_MATRIX_ROWS +
NEO_MATRIX_ZIGZAG`. The library uses this to convert the coordinates itself,
so that position 1 is on the left and row 1 at the top, and text scrolls
through the right way round. If the matrix is ever installed differently, only
this line needs to be adjusted.

### Win and lose screen

Both final screens alternate between a scrolling text and a still image until
the button is pressed:

- **Scrolling text:** “YOU WIN!” in green resp. “YOU LOSE” in red.
- **Still image:** at the top the correct solution as four large 3×3 color
  blocks. Below it, when winning, the **number of attempts needed** as a green
  number; when losing, a **red X**.

Pressing the button starts a new game from either screen.

---

## 4. Structure of the code

The sketch is organized as a **state machine**. There is always exactly one
active state, and `loop()` calls the matching function depending on the state:

```
      Start
        │  Button
        ▼
   ┌─► Game ───── all green ──────► Won ───────┐
   │    │                                      │ Button
   │    └──── MAX_ATTEMPTS reached ► Lost ──────┤
   └───────────────◄─── new game ──────────────┘
```

| State | Constant | Function in `loop()` |
|---|---|---|
| Start screen | `S_START` | `loopStart()` |
| Running game | `S_GAME` | `loopGame()` |
| Win screen | `S_WON` | `loopEnd()` |
| Lose screen | `S_LOST` | `loopEnd()` |

### The most important functions

**Flow / states**

- `setup()` – initializes the matrix, the button interrupt and the four
  readers (first all `PCD_Init()` calls, then `applyRfidSettings()` and
  antenna-off, so no later init resets these settings), and enters the
  start screen.
- `loop()` – dispatches to the three loop functions depending on `state`.
- `loopStart()` – shows the colorful start scrolling text “MASTERMIND - PRESS BUTTON”; a button press calls `newGame()`.
- `loopGame()` – polls the readers, updates the display, lets the row blink
  and reacts to the button.
- `loopEnd()` – alternates between the final scrolling text and the solution
  image; the button starts a new game.

**Game logic**

- `newGame()` – generates the secret sequence and resets everything.
- `confirmAttempt()` – checks whether confirmation is allowed, evaluates the
  attempt, draws the result, increments `attemptCount` and decides between
  win/lose/continue.
- `evaluate(attempt, green, yellow)` – the actual Mastermind evaluation
  (green = color + position, yellow = color only). Handles duplicate colors
  correctly via two count fields.
- `inputComplete()` / `inputConfirmable()` – check whether all four readers
  are occupied resp. whether the input is also different from the last
  attempt. Only then does the row blink and the button get accepted.

**RFID**

- `readAllChips(reader, uids)` – polls a single reader and reads all chips
  in its field (with `CHIP_LOCK = false` only the first). Only the antenna
  of the reader currently being polled is ever active; this prevents mutual
  interference and relieves the 3.3 V regulator.
- `setTxPower(i, step)` – sets the transmitter power of one reader.
- `findColor(uid)` – looks up the UID in the chip table and returns the color
  index (unknown → 0 = White).
- `applyRfidSettings()` – writes the current gain and transmitter power
  step to all four readers.
- `serialTuning()` – (only with `DEBUG 1`) reads the commands `g0`–`g5`,
  `t1`–`t8` and `?` from the Serial Monitor.
- `pollReaders(fresh)` – one complete round: read all readers, assign the
  chips, update the display state. Returns `true` if a displayed color has
  changed. `fresh = true` ignores remembered power-test results (used
  before confirming).
- `updateReader(i, uid)` – encapsulates new detection, chip swap and the
  failed-read counter against dropouts for one reader.

**Chip lock**

- `resolveOwners(owner, fresh)` – assigns every chip seen in the round to
  at most one reader (elimination, then power test).
- `decideContested(uid, mask, fresh)` – power test for a chip seen by
  several readers, with the remembered results (`probeCache`).
- `decideOnReader(...)` – several chips that can only belong to the same
  reader: keep the current one, otherwise power test.
- `probeThreshold(i, uid)` – lowest transmitter power step at which reader
  `i` still sees the chip (binary search).

**Display**

- `setLED(row, position, color)` – sets one LED (coordinates from 1).
- `drawInputRow()` – draws the current input row, including the blink state.
- `drawFeedback(row, green, yellow)` – paints the green/yellow/off LEDs.
- `drawEndImage()` – solution blocks plus attempt count resp. red X.
- `scrollTextStep(text, color)` – draws **one** step of a scrolling text
  (non-blocking) and reports when the text has run through completely.

**Button**

- `buttonISR()` – interrupt routine at pin 2. Detects a real press via
  edge + debounce and remembers the moment (`micros()`).
- `fetchButton()` – hands a pending press to the main program and resets the
  flag; also used to discard old presses.

### Why an interrupt for the button?

When no chip is present, each reader waits for a timeout. A full polling round
can therefore take more than 100 ms – with the chip lock and all readers
occupied about 250–300 ms, during a power test even longer. A short click that falls exactly within
that time would be missed with a simple `digitalRead()`. Pin 2 is
interrupt-capable, so the press is captured via an interrupt and buffered
safely – no button press is lost, guaranteed.

On the Mega the interrupt-capable pins are D2, D3, D18, D19, D20 and D21.
`attachInterrupt(digitalPinToInterrupt(BUTTON_PIN), …)` translates the pin
number into the right interrupt number itself (pin 2 is interrupt 0 on the
Mega as well, internally INT4), so nothing has to be changed in the code if
the button is moved to another of these pins.

### Randomness and memory

- **Randomness:** The moment of the very first button press (`micros()`)
  serves as the seed for the random number generator. This is practically
  unpredictable, so the secret sequence reliably differs from game to game.
- **Memory:** The Mega has 8 KB of RAM (the UNO only 2 KB), of which the
  matrix occupies 768 bytes. The chip table (`CHIPS[]`) and all texts still
  live in flash (`PROGMEM`) instead of in RAM. On the Mega this is no longer
  strictly necessary, but it costs nothing and leaves RAM free for later
  extensions. Already-played attempts are not stored separately – they are
  on the matrix anyway.

### Memory usage (Arduino Mega 2560 / ATmega2560)

Measured with Arduino AVR core 1.8.6:

| Variant | Flash (of 248 KB) | RAM (incl. 768-byte matrix buffer at runtime) |
|---|---|---|
| `DEBUG 1` | 23 780 bytes ≈ 9 % | 1 568 bytes ≈ 19 % |
| `DEBUG 0` | 20 530 bytes ≈ 8 % | 1 513 bytes ≈ 18 % |

The chip lock needs about 3 KB of flash and about 100 bytes of RAM. With
more than 6 KB of free RAM there is plenty of room for the stack and for
extensions (e.g. the two reserved buttons, more readers, sound).

The RAM figure reported by the Arduino IDE is lower (800 resp. 745 bytes)
because it does not yet include the matrix buffer – that is only allocated
at runtime.

---

## 5. Wiring (Arduino Mega 2560)

The complete schematic is in `mastermind.kicad_sch`. In the sketch, the pins
are defined at the top under *Pins*.

Schematic – Arduino Mega 2560 version

### Pin assignment

| Mega pin | Signal | Connected to | Note |
|---|---|---|---|
| D2 | `BTN1` | Button 1 (confirm) → GND | interrupt pin, `INPUT_PULLUP`, pressed = LOW |
| D3 | `BTN2` | Button 2 → GND | reserved, not used by the firmware yet (interrupt pin) |
| D5 | `LED_DIN` | LED matrix DATA/DIN | |
| D6 | `SS4` | Reader 4 SDA | |
| D7 | `SS3` | Reader 3 SDA | |
| D8 | `SS2` | Reader 2 SDA | |
| D9 | `RST` | RST of all 4 readers | shared |
| D10 | `SS1` | Reader 1 SDA | |
| D18 | `BTN3` | Button 3 → GND | reserved, not used by the firmware yet (interrupt pin; TX1, free as long as `Serial1` is not used) |
| D50 | `MISO` | MISO of all 4 readers | hardware SPI, shared |
| D51 | `MOSI` | MOSI of all 4 readers | hardware SPI, shared |
| D52 | `SCK` | SCK of all 4 readers | hardware SPI, shared |
| D53 | – | not connected | hardware SS, stays an output (`SPI.begin()`) |
| 3.3V | `+3V3` | 3.3V of all 4 readers | **not 5 V!** |
| 5V | `+5V` | LED matrix 5V | see "Power supply" |
| GND | `GND` | readers, matrix, buttons | common ground |
| D0 / D1 | – | not connected | USB serial (Serial Monitor) |

The IRQ pins of the readers are not used.

### Changes compared to the UNO wiring

- **SPI moves:** on the Mega the hardware SPI is on D50 (MISO), D51 (MOSI)
  and D52 (SCK) – *not* on D11/D12/D13 as on the UNO. The same three signals
  are also available on the 6-pin ICSP header. If the readers stay connected
  to D11–D13, they are not detected (firmware version `0x00` or `0xFF` in the
  Serial Monitor).
- **Button 3 moves** from D4 to D18, so all three buttons are on
  interrupt-capable pins (on the Mega: D2, D3, D18, D19, D20, D21).
- All other signals (SS1–SS4, RST, LED_DIN, button 1 and 2) keep their pin
  numbers.
- In the Arduino IDE select **Tools → Board → "Arduino Mega or Mega 2560"**
  (processor ATmega2560). If another board is selected, the sketch stops at
  compile time with `Wrong board selected` on purpose.

### Power supply

- The RC522 readers run on **3.3 V only**. The Mega's 3.3 V pin (onboard
  regulator, approx. 150 mA) is enough because only one reader antenna is
  switched on at any time.
- At low brightness (`BRIGHTNESS = 4`) the matrix can run from the Mega's
  5 V pin. For higher brightness use an external 5 V power supply for the
  matrix and connect its ground to the Mega's GND (common ground!).

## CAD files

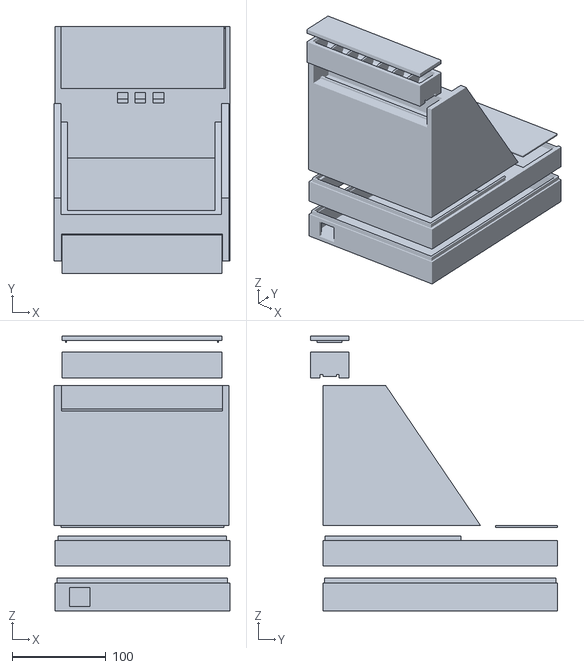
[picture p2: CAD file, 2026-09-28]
3D_models/whole project.stl
187.0 x 263.6 x 293.0

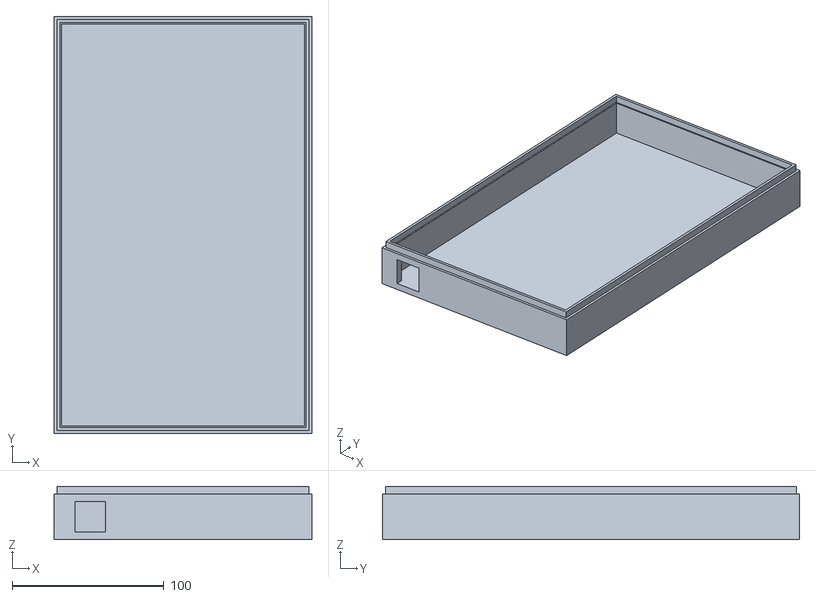
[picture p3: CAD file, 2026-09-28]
3D_models/Layer 1 - Ground.stl
170.0 x 275.0 x 35.0

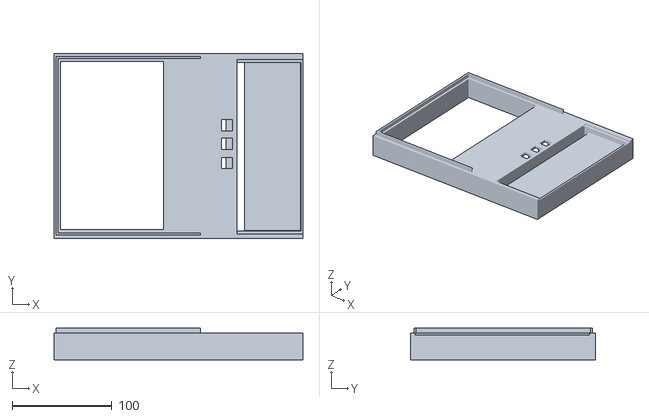
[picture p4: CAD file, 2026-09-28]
3D_models/Layer 2.stl
250.1 x 186.0 x 32.0

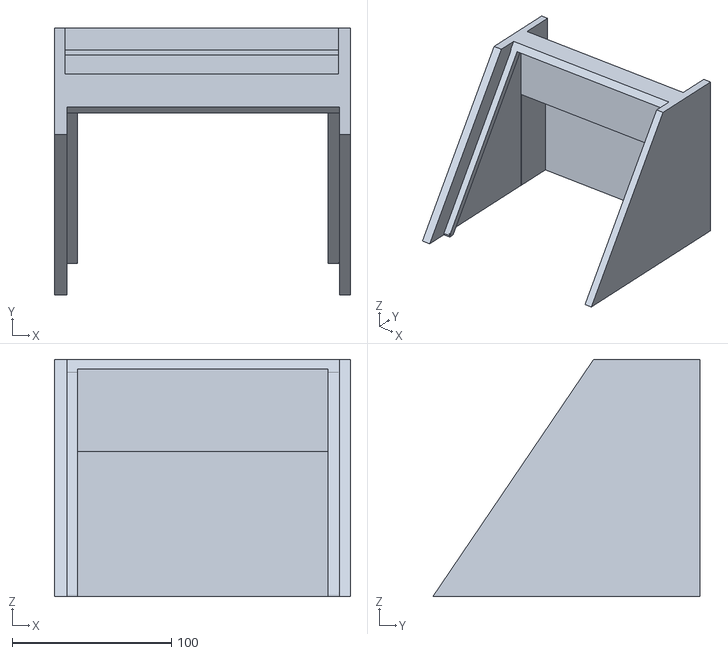
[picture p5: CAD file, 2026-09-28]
3D_models/Layer 3.stl
186.0 x 168.0 x 149.0

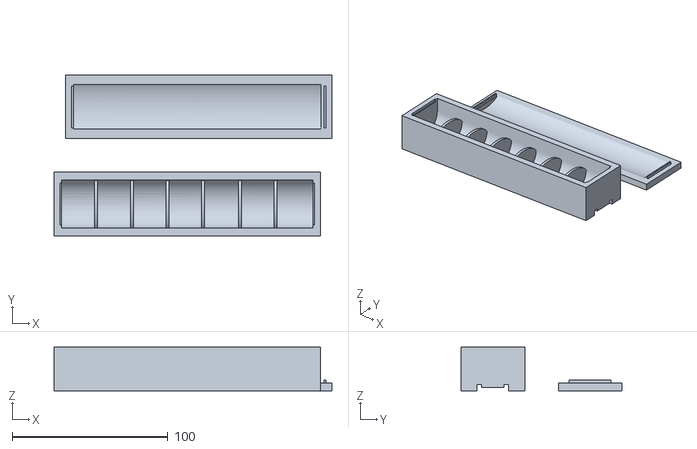
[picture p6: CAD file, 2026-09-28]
3D_models/Chipbox.stl
178.4 x 103.5 x 28.0

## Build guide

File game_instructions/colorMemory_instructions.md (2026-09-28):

# Color Memory

Memorize a color sequence and rebuild it with your chips. Every round adds one color.

## How to play

1. **Watch:** A new random sequence of Red, Green, Blue and Yellow is shown on the grid. Round 1 has 1 color, round 2 has 2, and so on (max. 20). The sequence is completely new each round, not an extension of the last one. The longer it is, the longer it stays visible. Then all used places turn white, so you see how many colors you need but no longer which ones.
2. **Enter in blocks of four:** Each grid row is one block. Readers 1–4 match positions 1–4 of the current row. In the last block, only as many readers as colors remain are active. Chips on the other readers are ignored.
3. **Confirm the block:** When every required reader has a known chip, the row blinks. Press **button 1** to confirm. The block stays visible in its colors.
4. **Clear the readers:** Remove your chips before entering the next block. Until then, button 1 is ignored. This lets you reuse the same chips within one sequence and prevents accidental double confirmations.
5. **Get your result:** After the last block, every position is compared to the sequence:
   - 🟢 **Green** = correct (+1 point)
   - 🔴 **Red** = wrong

   If everything is green, the next round starts. If at least one position is wrong, the game is over.

## Scoring

You score 1 point per correct position across **all rounds**, including the failed last round.
Example: rounds 1–3 perfect, then 2 of 4 correct in round 4 → 1 + 2 + 3 + 2 = **8 points**.

## Game over

The screen alternates between "GAME OVER" and your score. **Button 1** starts a new game. **Button 2 or 3** switches the game.

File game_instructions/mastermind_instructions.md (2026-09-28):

# Mastermind

The Arduino picks a secret sequence of four colors: **Red, Green, Blue, Yellow**. Colors can repeat. Find the sequence!

## How to play

1. **Place chips:** Put a chip on each of the four readers. The current row shows their colors (white = no or unknown chip).
2. **Confirm:** When all four chips are recognized, the row blinks. Press **button 1** to confirm.
3. **Read the result:** Four LEDs to the right show how close you are:
   - 🟢 **Green** = right color, right position
   - 🟡 **Yellow** = right color, wrong position
   - ⚫ **Off** = no hit

   The LEDs are sorted (green first, then yellow), so their order does *not* tell you which position was right.
4. **Try again:** Your next guess goes into the next row.

Every chip in the secret sequence counts only once. With the secret **Red · Red · Green · Blue**, the guess **Red · Green · Green · Blue** gives 3 green and 0 yellow, because the second Green has no match left.

## Win or lose

- **Win:** All four result LEDs are green.
- **Lose:** You run out of attempts.

Button 1 starts a new game.

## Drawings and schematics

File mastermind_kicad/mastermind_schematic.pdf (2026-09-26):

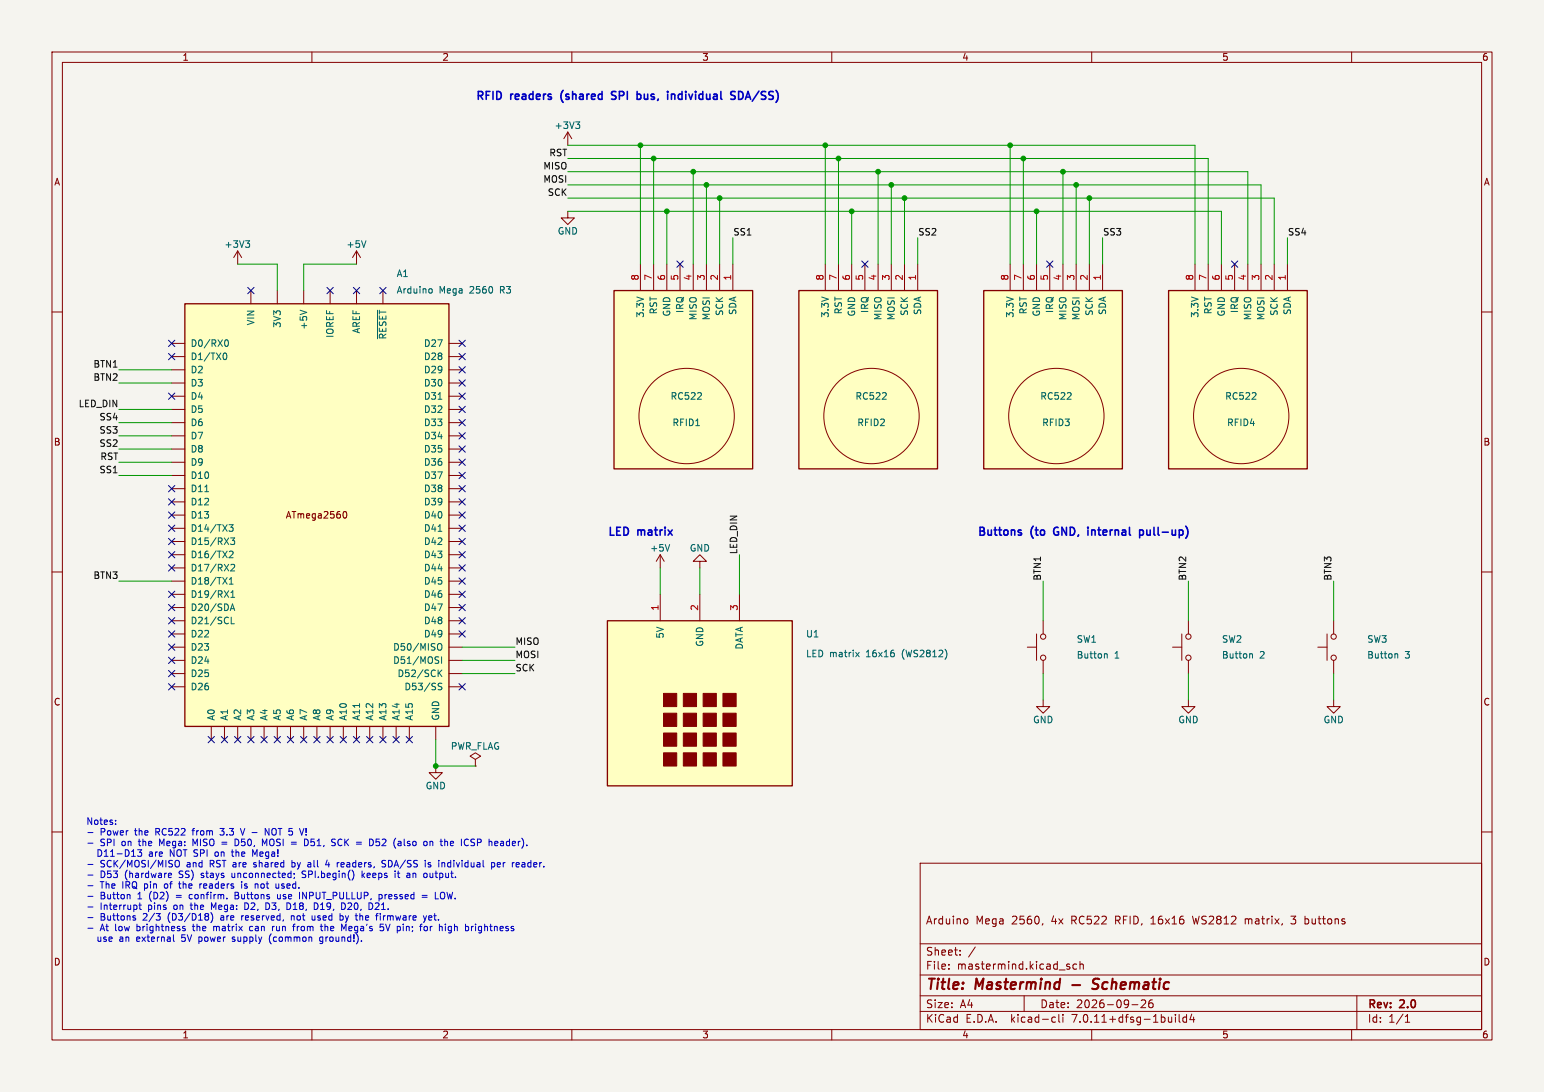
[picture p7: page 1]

Id: 1/1 Title: Mastermind - Schematic

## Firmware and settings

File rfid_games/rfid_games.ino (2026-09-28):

/* =========================================================================
   RFID GAMES: MASTERMIND + COLOR MEMORY GAME
   4 RFID readers (RC522), 16x16 LED matrix and 3 buttons
   -------------------------------------------------------------------------
   Two games share the same hardware. Button 2 selects Mastermind,
   button 3 selects the Color Memory Game, button 1 starts a game and
   confirms inputs. After switching on, Mastermind is selected.

   Game selection:
     On the start and end screens a short press of button 2 / 3 shows the
     start screen of the selected game.
     During a running game a short press of button 2 / 3 is ignored, so an
     accidental press never ends a game. To quit a running game, HOLD
     button 2 or 3 for ABORT_HOLD_TIME (3 s): the game is ended and the
     start screen of the selected game appears.

   MASTERMIND
     The Arduino picks a secret sequence of 4 colors
     (Red / Green / Blue / Yellow, colors may repeat).
     The player places a color chip on each of the 4 readers and confirms
     with button 1. The feedback appears to the right:
       Green  = right color in the right position
       Yellow = right color, but wrong position
     The feedback is NOT position-based: first all green, then all yellow
     LEDs, the rest stay off.

     Flow:
       1. Start screen (scrolling text "MASTERMIND - PRESS BUTTON"). Press
          button 1 -> the game starts.
          The moment the button is pressed serves as the random seed.
       2. Attempt 1 is in row 1, attempt 2 in row 2, and so on.
          - No chip on a reader   -> LED white
          - Chip present          -> LED in the chip color
          - All 4 occupied        -> row blinks, button 1 confirms
          If the input is identical to the last attempt, nothing blinks
          and the button is ignored (protection against double confirmation).
       3. All 4 correct -> win screen, after MM_MAX_ATTEMPTS -> lose screen.
       4. Win/lose screen: scrolling text, then the solution as 4 color
          blocks (win: below it the number of attempts, lose: a red X).
          Scrolling texts: "YOU WIN!" resp. "YOU LOSE".
          Button 1 -> new game.

     Matrix layout (row/position counted from 1):
       Row 1..MM_MAX_ATTEMPTS, position 3-6   : inputs
       Row 1..MM_MAX_ATTEMPTS, position 10-13 : feedback
       Row 16, position 10-13                 : solution (only if MM_DEBUG_SHOW_SOLUTION)

   COLOR MEMORY GAME
     Every round the Arduino generates a COMPLETELY NEW random sequence
     (the old one is not extended). Round 1 has 1 color, round 2 has 2
     colors, and so on up to CM_MAX_LENGTH (20). After that every round
     has 20 colors (endless).

     Flow:
       1. Start screen (scrolling text "COLOR MEMORY GAME - PRESS BUTTON").
          Button 1 -> round 1 starts (random seed = moment of the press).
       2. The whole sequence is shown at once on a grid of 5 rows x 4
          positions. Sequence position n has a fixed place:
          grid row = n / 4, grid position = n % 4. The display time grows
          with the length (CM_SHOW_TIME_BASE + CM_SHOW_TIME_PER_COLOR per
          color). Then all used grid places turn white.
       3. Input in blocks of 4: reader 1..4 = position 1..4 of the current
          grid row. The last block only needs as many readers as colors are
          left; the readers not needed are not read at all and can never
          get a chip (-> no cross-reading onto an empty reader, see
          activeReaderCount()). When all required readers carry a known chip, the row
          blinks and button 1 confirms the block. Confirmed blocks stay
          visible in their colors. Before the next block can be confirmed,
          the chips have to be removed from the required readers (this
          also prevents a double confirmation).
       4. Only after the complete sequence has been entered is it compared
          position by position: directly below every color a green (correct)
          or red (wrong) LED appears. Every correct position = 1 point. The
          score adds up over all rounds of a game.
       5. Everything correct -> next round. At least one wrong position ->
          Game over screen: scrolling text "GAME OVER", then the score.
          Button 1 -> new game.

     Matrix layout (row/position counted from 1):
       Grid positions 2, 6, 11, 15
       Input rows 2, 5, 8, 11, 14 - feedback directly below: 3, 6, 9, 12, 15

   Colors: index in colors[]
       0 = White (no / unknown chip)
       1 = Red,  2 = Green,  3 = Blue,  4 = Yellow

   WIRING (Arduino Mega 2560)
     Shared across all 4 readers (hardware SPI of the Mega):
       SCK   -> Pin 52
       MOSI  -> Pin 51
       MISO  -> Pin 50
       RST   -> Pin 9
       3.3V  -> 3.3V     (NOT 5V!)
       GND   -> GND
       SCK/MOSI/MISO are also available on the 6-pin ICSP header.
       Pins 11/12/13 are NOT connected to SPI on the Mega!
     Individually per reader:
       SDA/SS reader 1 -> Pin 10
       SDA/SS reader 2 -> Pin 8
       SDA/SS reader 3 -> Pin 7
       SDA/SS reader 4 -> Pin 6
     LED matrix:
       DIN   -> Pin 5
     Buttons (one contact -> pin, other contact -> GND,
     internal pullup, pressed = LOW, all interrupt-capable):
       Button 1 (start / confirm)          -> Pin 2
       Button 2 (select Mastermind)        -> Pin 3
       Button 3 (select Color Memory Game) -> Pin 18 (TX1, free as long as
                                              Serial1 is not used)
     Pin 53 (hardware SS) stays unconnected. It must remain an OUTPUT so
     the Mega stays SPI master - SPI.begin() takes care of that.
   ========================================================================= */

// This sketch and its pin assignment are made for the Mega 2560.
// Select "Arduino Mega or Mega 2560" under Tools > Board.
#if !defined(__AVR_ATmega2560__)
#error "Wrong board selected: this sketch is wired for the Arduino Mega 2560."
#endif

#include <SPI.h>
#include <MFRC522.h>
#include <Adafruit_GFX.h>
#include <Adafruit_NeoMatrix.h>
#include <Adafruit_NeoPixel.h>
#include <Fonts/TomThumb.h>   // small 3x5 font for numbers with 3-4 digits
#include <avr/pgmspace.h>

// ============================== Settings =================================

// 1 = serial output on (read UIDs, solution, feedback)
// 0 = off (saves memory, for the finished game)
#define DEBUG 1

// ------------------------------ Mastermind -------------------------------

// true = show the secret sequence in row 16 during the game (for testing)
const bool MM_DEBUG_SHOW_SOLUTION = false;

// Maximum number of attempts, after which the game is lost
const byte MM_MAX_ATTEMPTS = 10;
static_assert(MM_MAX_ATTEMPTS >= 1 && MM_MAX_ATTEMPTS <= 15,
              "MM_MAX_ATTEMPTS must be between 1 and 15 (row 16 is reserved for the debug solution)");

// -------------------------- Color Memory Game ----------------------------

// Maximum length of the memory sequence (grid: 5 rows x 4 positions).
// Once reached, every further round has this length (endless).
const byte CM_MAX_LENGTH = 20;

// Times in milliseconds
const unsigned int CM_SHOW_PAUSE          = 300;   // dark pause before the sequence appears
const unsigned int CM_SHOW_TIME_BASE      = 2000;  // display time of the sequence ...
const unsigned int CM_SHOW_TIME_PER_COLOR = 500;   // ... plus this much per color

// ------------------------------- Shared ----------------------------------

// Matrix brightness (0..255)
const byte BRIGHTNESS = 4;

// Times in milliseconds
const unsigned int BLINK_INTERVAL     = 250;   // blinking of a complete input
const unsigned int SCROLL_INTERVAL    = 70;    // speed of the scrolling texts (smaller = faster)
const unsigned int END_IMAGE_DURATION = 4000;  // how long the end image stays
const unsigned int RESULT_PAUSE       = 1500;  // show the last feedback before the next screen
const byte         DEBOUNCE_TIME      = 30;    // button debounce
const unsigned int ABORT_HOLD_TIME    = 3000;  // hold button 2 / 3 this long to quit a running game

// --------------------------------- Pins ----------------------------------

// Hardware SPI of the Mega (fixed, set up by SPI.begin(), listed here
// only for reference): MISO = 50, MOSI = 51, SCK = 52, SS = 53.

const byte MATRIX_PIN = 5;

// Buttons. All pins are interrupt-capable on the Mega (D2, D3, D18-D21).
const byte BUTTON_COUNT        = 3;
const byte BUTTON_CONFIRM      = 0;   // button 1: start / confirm
const byte BUTTON_MASTERMIND   = 1;   // button 2: select Mastermind
const byte BUTTON_COLOR_MEMORY = 2;   // button 3: select Color Memory Game

// Pin 18 = TX1, free as long as Serial1 is not used
const byte BUTTON_PINS[BUTTON_COUNT] = { 2, 3, 18 };

const byte READER_COUNT = 4;   // = length of a Mastermind sequence / of an input block

const byte RST_PIN  = 9;   // shared by all readers
const byte SS_PIN_1 = 10;
const byte SS_PIN_2 = 8;
const byte SS_PIN_3 = 7;
const byte SS_PIN_4 = 6;

// ----------------------------- RFID timing -------------------------------

// Length of the UID in bytes. Most MIFARE Classic chips have 4 bytes.
const byte UID_LENGTH = 4;

// This many failed reads in a row before "chip removed" is assumed.
const byte MAX_FAILED_READS = 3;

// Pause between two complete polling rounds (ms)
const unsigned int POLL_INTERVAL = 30;

// Wait time after switching on an antenna (ms).
// If chips are detected unreliably: increase this first (e.g. to 10).
const byte ANTENNA_WAIT = 5;

// Gain and transmitter power are set INDIVIDUALLY for every reader, because
// the modules differ. The values were found with rfid_sweep_test.ino
// (block "RECOMMENDED SETTINGS"); repeat the test after changing the
// hardware (module swapped, readers moved, other chips).

// Receiver gain per reader (step 0..5). Lower = shorter range.
// The RC522 only knows these 6 values, there are no steps in between:
//   step:   0      1      2      3      4      5
//   gain:  18 dB  23 dB  33 dB  38 dB  43 dB  48 dB
//                        ^ library default after PCD_Init()
//                                     reader:  1  2  3  4
constexpr byte RFID_GAIN_STEP[READER_COUNT] = { 2, 2, 1, 1 };

// Transmitter power per reader (step 1..8), i.e. the strength of the field
// itself. Step 8 = library default (full power).
// The library has no function for this, so the driver conductance registers
// are written directly: CWGsP = step * 4, CWGsN = step
// (step 8 -> 0x20 / 0x8 = reset values, step 4 -> 0x10 / 0x4, ...).
// The field does not drop linearly: neighboring steps may hardly differ,
// below a certain step detection stops abruptly.
//                                     reader:  1  2  3  4
constexpr byte TX_POWER_STEP[READER_COUNT]  = { 2, 1, 1, 2 };

// Gain used by ALL readers during the power test of the chip lock. The test
// then searches the transmitter power steps 1..8 on every reader, so the
// results of different readers stay comparable although their normal
// settings differ. Step 2 = 33 dB = library default.
const byte PROBE_GAIN_STEP = 2;

// All values can also be changed at runtime via the Serial Monitor
// (DEBUG 1): "g<reader><step>" = gain, "t<reader><step>" = transmitter
// power, reader 0 = all readers, "?" = show current settings.
// Enter the values found afterwards here.

const byte GAIN_STEP_COUNT = 6;
const byte TX_STEP_MAX     = 8;

// Checks every entry of RFID_GAIN_STEP / TX_POWER_STEP at compile time
constexpr bool rfidStepsValid(byte i) {
  return i >= READER_COUNT ||
         (RFID_GAIN_STEP[i] < GAIN_STEP_COUNT &&
          TX_POWER_STEP[i] >= 1 && TX_POWER_STEP[i] <= TX_STEP_MAX &&
          rfidStepsValid(i + 1));
}
static_assert(rfidStepsValid(0),
              "RFID_GAIN_STEP must be 0..5 and TX_POWER_STEP 1..8 for every reader");
static_assert(PROBE_GAIN_STEP < GAIN_STEP_COUNT, "PROBE_GAIN_STEP must be 0..5");

// Read errors (see readReader()): if a reader gets an answer it cannot
// decode - typically its own chip plus the weak answer of a chip on the
// neighbor reader, which garbles it - the reader immediately reads again
// with less gain, one step at a time down to this gain step. The weak
// neighbor chip drops below the receiver threshold first, the own chip
// directly on the antenna is still read. 0 = down to 18 dB.
const byte FALLBACK_MIN_GAIN_STEP = 0;
static_assert(FALLBACK_MIN_GAIN_STEP < GAIN_STEP_COUNT, "FALLBACK_MIN_GAIN_STEP must be 0..5");

// Chip lock against cross-reading (see documentation, "Chip lock").
// true  = every chip is assigned to exactly one reader, even if several
//         readers see it. Costs a little time per polling round.
// false = every reader simply shows the first chip it sees (old behavior).
const bool CHIP_LOCK = true;

// Max. number of chips read per reader and round
// (its own chip + chips of neighbors that reach into its field)
const byte MAX_CHIPS_PER_READER = 3;

// How long a decision of the power test stays valid (ms).
// Before a button confirmation the test is always repeated.
const unsigned int PROBE_CACHE_TIME = 3000;

// ------------------------------ Layout -----------------------------------

// --- Mastermind ---

// Columns (position from 1) of the input - readers 1..4
const byte MM_READER_LED_POSITION[READER_COUNT] = { 3, 4, 5, 6 };

// Columns (position from 1) of the feedback
const byte MM_FEEDBACK_POSITION[READER_COUNT] = { 10, 11, 12, 13 };

// Row for the debug display of the solution
const byte MM_SOLUTION_DEBUG_ROW = 16;

// --- Color Memory Game ---
// Grid of CM_ROW_COUNT rows x 4 positions. Sequence position n (from 0)
// lies in grid row n / 4 at grid position n % 4.

const byte CM_ROW_COUNT = 5;

// Columns (position from 1) of the grid - readers 1..4
const byte CM_GRID_POSITION[READER_COUNT] = { 2, 6, 11, 15 };

// Rows (from 1) of the colors and of the feedback directly below them
const byte CM_INPUT_ROW[CM_ROW_COUNT]    = { 2, 5, 8, 11, 14 };
const byte CM_FEEDBACK_ROW[CM_ROW_COUNT] = { 3, 6, 9, 12, 15 };

static_assert(CM_MAX_LENGTH >= 1 && CM_MAX_LENGTH <= CM_ROW_COUNT * READER_COUNT,
              "CM_MAX_LENGTH must be between 1 and 20 (grid of 5 rows x 4 positions)");

// ------------------------------ Colors -----------------------------------

const byte COLOR_COUNT = 5;

const byte COLOR_WHITE  = 0;
const byte COLOR_RED    = 1;
const byte COLOR_GREEN  = 2;
const byte COLOR_BLUE   = 3;
const byte COLOR_YELLOW = 4;

byte colors[COLOR_COUNT][3] =
{
  {255, 255, 220},  // 0 White
  {255,   0,   0},  // 1 Red
  {  60, 255,  120},  // 2 Green
  {  0,   0, 255},  // 3 Blue
  {255, 220,   0}   // 4 Yellow
};

const byte OFF[3] = { 0, 0, 0 };

// ------------------------------ Texts ------------------------------------
// Texts on the matrix. Stored in flash (PROGMEM) instead of RAM.

const char TEXT_MM_START[]     PROGMEM = "MASTERMIND - PRESS BUTTON";
const char TEXT_MM_WIN[]       PROGMEM = "YOU WIN!";
const char TEXT_MM_LOSE[]      PROGMEM = "YOU LOSE";
const char TEXT_CM_START[]     PROGMEM = "COLOR MEMORY GAME - PRESS BUTTON";
const char TEXT_CM_GAME_OVER[] PROGMEM = "GAME OVER";

// Default font: 5x7 pixels, 6 pixels wide including spacing
const byte CHAR_WIDTH = 6;
const byte TEXT_Y = 4;          // scrolling text vertically centered (rows 5-11)

// ------------------------- Chip-color table ------------------------------
// Enter the UIDs of your 16 chips here, followed by the color index (1..4).
// The table is stored in flash (PROGMEM) and thereby saves 80 bytes of RAM.

struct Chip {
  byte uid[UID_LENGTH];
  byte color;             // index in colors[]
};

const Chip CHIPS[] PROGMEM = {
  // ---- Red (1) ----
  { {0x04, 0x34, 0x13, 0xBB}, 1 },
  { {0x04, 0x6A, 0x21, 0xBB}, 1 },
  { {0x04, 0x84, 0xFD, 0xBA}, 1 },
  { {0x04, 0x36, 0x13, 0xBB}, 1 },
  // ---- Green (2) ----
  { {0x04, 0x99, 0x32, 0xBB}, 2 },
  { {0x04, 0x42, 0x26, 0xBB}, 2 },
  { {0x04, 0x71, 0x21, 0xBB}, 2 },
  { {0x04, 0x53, 0x3C, 0xBB}, 2 },
  // ---- Blue (3) ----
  { {0x04, 0xD4, 0x36, 0xBB}, 3 },
  { {0x04, 0x9A, 0x3D, 0xBB}, 3 },
  { {0x04, 0x7F, 0x31, 0xBB}, 3 },
  { {0x04, 0xB1, 0x1B, 0xBB}, 3 },
  // ---- Yellow (4) ----
  { {0x04, 0x5B, 0x12, 0xBB}, 4 },
  { {0x04, 0xE6, 0x17, 0xBB}, 4 },
  { {0x04, 0x4F, 0x26, 0xBB}, 4 },
  { {0x04, 0xA6, 0x1C, 0xBB}, 4 }
};

const byte CHIP_COUNT = sizeof(CHIPS) / sizeof(CHIPS[0]);

// ------------------------------ Objects ----------------------------------

// Pixel 0 sits top RIGHT, the first row runs to the left (zigzag).
// This makes position 1 the left one and text is displayed the right way up.
Adafruit_NeoMatrix matrix = Adafruit_NeoMatrix(
  16, 16, MATRIX_PIN,
  NEO_MATRIX_TOP + NEO_MATRIX_RIGHT +
  NEO_MATRIX_ROWS + NEO_MATRIX_ZIGZAG,
  NEO_GRB + NEO_KHZ800
);

MFRC522 reader[READER_COUNT] = {
  MFRC522(SS_PIN_1, RST_PIN),
  MFRC522(SS_PIN_2, RST_PIN),
  MFRC522(SS_PIN_3, RST_PIN),
  MFRC522(SS_PIN_4, RST_PIN)
};

// ------------------------------- State -----------------------------------

// States - Mastermind
const byte S_MM_START     = 0;   // start screen
const byte S_MM_GAME      = 1;   // running game
const byte S_MM_WON       = 2;   // win screen
const byte S_MM_LOST      = 3;   // lose screen
// States - Color Memory Game
const byte S_CM_START     = 4;   // start screen
const byte S_CM_SHOW      = 5;   // sequence is being shown
const byte S_CM_INPUT     = 6;   // player enters the sequence
const byte S_CM_GAME_OVER = 7;   // game over screen

byte state = S_MM_START;

// Mastermind
byte mmSecretCode[READER_COUNT];   // color indices 1..4
byte mmLastAttempt[READER_COUNT];  // last confirmed input (0 = none yet)
byte mmAttemptCount = 0;           // number of attempts already confirmed

// Color Memory Game
byte cmSequence[CM_MAX_LENGTH];    // color indices 1..4
byte cmInput[CM_MAX_LENGTH];       // confirmed input of the player
byte cmLength = 0;                 // length of the current sequence
byte cmInputPosition = 0;          // number of colors already confirmed
unsigned int cmScore = 0;          // correct positions over all rounds
bool cmWaitForEmpty = false;       // chips of the last block still have to be removed
bool cmSequenceVisible = false;    // S_CM_SHOW: false = dark pause, true = sequence visible
unsigned long cmShowSince = 0;     // start of the current S_CM_SHOW phase

// Blinking
bool blinkOn = true;
unsigned long lastBlinkToggle = 0;

// Scrolling text / end screen
int16_t scrollX = 16;
unsigned long lastScrollStep = 0;
bool endImageActive = false;
unsigned long endImageSince = 0;

// Reader
byte gainStep[READER_COUNT];   // current settings per reader (changeable via serial),
byte txStep[READER_COUNT];     // loaded from RFID_GAIN_STEP / TX_POWER_STEP in setup()
byte readerColor[READER_COUNT];             // color index per reader
byte currentUid[READER_COUNT][UID_LENGTH];  // UID of the chip currently present
bool chipPresent[READER_COUNT];             // is a chip currently present?
byte failedReads[READER_COUNT];             // counter for dropouts

// Chip lock
const byte NO_READER    = 0xFF;
const byte NO_THRESHOLD = 0xFF;
const byte MAX_UIDS     = READER_COUNT * MAX_CHIPS_PER_READER;

// All chips each reader saw in the current polling round
byte seenCount[READER_COUNT];
byte seenUid[READER_COUNT][MAX_CHIPS_PER_READER][UID_LENGTH];

// Remembered results of the power test (one entry per contested chip)
struct ProbeResult {
  byte uid[UID_LENGTH];
  byte mask;              // readers that competed (bit 0 = reader 1)
  byte winner;            // reader index or NO_READER (tie)
  unsigned long time;     // millis() of the test
  bool valid;
};
ProbeResult probeCache[READER_COUNT];

// Buttons (written inside the interrupts -> volatile)
volatile bool buttonPressed[BUTTON_COUNT];
volatile unsigned long lastButtonEdge[BUTTON_COUNT];
volatile unsigned long buttonTimeIsr[BUTTON_COUNT];   // micros() at press
volatile unsigned long buttonPressMillis[BUTTON_COUNT]; // millis() at press (for holding)
volatile bool buttonHoldUsed[BUTTON_COUNT];           // this press may no longer count as "held"
unsigned long buttonTime = 0;                         // copy for the main program

// ============================== Buttons ==================================

// Called on every level change at a button pin.
// A press only counts if the pin is LOW and the last edge is longer ago
// than DEBOUNCE_TIME. The bouncing on press AND on release produces edges
// in quick succession and is thereby ignored.
void handleButtonEdge(byte b) {
  unsigned long now = millis();
  if (digitalRead(BUTTON_PINS[b]) == LOW && (now - lastButtonEdge[b]) >= DEBOUNCE_TIME) {
    buttonPressed[b]     = true;
    buttonTimeIsr[b]     = micros();
    buttonPressMillis[b] = now;     // a new press starts a new hold
    buttonHoldUsed[b]    = false;
  }
  lastButtonEdge[b] = now;
}

// One interrupt routine per button (an ISR cannot take parameters)
void buttonConfirmISR()     { handleButtonEdge(BUTTON_CONFIRM); }
void buttonMastermindISR()  { handleButtonEdge(BUTTON_MASTERMIND); }
void buttonColorMemoryISR() { handleButtonEdge(BUTTON_COLOR_MEMORY); }

// Returns true if button b was pressed since the last call, and resets
// the flag. The moment of the press is copied to buttonTime.
// Can also be used to "discard" old presses.
bool fetchButton(byte b) {
  noInterrupts();
  bool pressed = buttonPressed[b];
  buttonPressed[b] = false;
  if (pressed) buttonTime = buttonTimeIsr[b];
  interrupts();
  return pressed;
}
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
void loop() {
#if DEBUG
  serialTuning();
#endif

  switch (state) {
    case S_MM_START:
    case S_CM_START:     loopStart();   break;
    case S_MM_GAME:      mmLoopGame();  break;
    case S_CM_SHOW:      cmLoopShow();  break;
    case S_CM_INPUT:     cmLoopInput(); break;
    case S_MM_WON:
    case S_MM_LOST:
    case S_CM_GAME_OVER: loopEnd();     break;
  }
}

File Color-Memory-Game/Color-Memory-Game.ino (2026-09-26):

/* =========================================================================
   COLOR MEMORY GAME (Simon-Says Variant) with 4 RFID Readers (RC522),
   16x16 LED Matrix and Button
   -------------------------------------------------------------------------
   STANDALONE FILE - independent from the Mastermind sketch.
   Uses the same hardware base (readers, matrix, button,
   chip color table).

   Game idea:
     The Arduino generates a COMPLETELY NEW color sequence every round
     (the old sequence is not extended, but a new one is generated).
     Round 1 contains exactly 1 color, round 2 exactly 2 colors, etc.,
     up to MAX_MEMORY_LENGTH (20) colors.

     GRID DISPLAY:
     The memory sequence is shown on a 5x4 grid of LED positions,
     arranged on the 16x16 matrix: 4 positions per row (one
     per reader), maximum 5 rows (5 x 4 = 20 = MAX_MEMORY_LENGTH).
     Each position of the memory sequence (index 0..19) has a FIXED
     position in the grid: row = index / 4, column = index % 4.
     The first 4 colors are therefore in row 1, colors 5-8 in row 2,
     etc.

     During playback, ALL LEDs of the current sequence are shown
     simultaneously at their fixed grid positions.

     INPUT:
     The player can place up to 4 chips simultaneously on the 4 readers
     (distributed as desired). During input, the currently "active" row
     is updated live with the colors detected by the RFID readers.
     The button confirms the current block and each position is compared
     with the memory sequence:
       - correct -> the corresponding LED flashes green, then white,
                    1 point
       - wrong   -> the corresponding LED flashes red, game over

     If the complete sequence is entered correctly, the next round
     begins: a new, longer sequence is generated and displayed.

     Points = total number of correctly entered colors
     accumulated across all rounds.

   Game flow:
     1. Start screen (scrolling text). Button -> game starts
        (round 1, 1 color).
        The button press time is used as the random seed.
     2. Generate a new sequence and display it on the grid
        (blocking, but the button interrupt continues running
        in the background - old button presses are discarded afterwards).
     3. Input mode: place up to 4 chips on the readers, button
        confirms the current block.
     4. On an error -> Game Over screen with score, button -> new game.
        If the complete sequence is correct -> next round
        (new, longer sequence).

   Colors: Index in colors[]
       0 = White (no / unknown chip)
       1 = Red, 2 = Green, 3 = Blue, 4 = Yellow

   WIRING (Arduino UNO)
     All 4 RFID readers are connected and used in the game:
     Shared by all 4 readers:
       SCK   -> Pin 13
       MOSI  -> Pin 11
       MISO  -> Pin 12
       RST   -> Pin 9
       3.3V  -> 3.3V     (NOT 5V!)
       GND   -> GND
     Individually per reader:
       SDA/SS Reader 1 -> Pin 10
       SDA/SS Reader 2 -> Pin 8
       SDA/SS Reader 3 -> Pin 7
       SDA/SS Reader 4 -> Pin 6
     LED matrix:
       DIN   -> Pin 5
     Button:
       one contact -> Pin 2, other contact -> GND
       (internal pullup, pressed = LOW)
   ========================================================================= */

#include <SPI.h>
#include <MFRC522.h>
#include <Adafruit_GFX.h>
#include <Adafruit_NeoMatrix.h>
#include <Adafruit_NeoPixel.h>
#include <avr/pgmspace.h>

// ============================ Settings ===================================

// 1 = serial output on (UID, memory sequence, score)
// 0 = off (saves memory, for the finished game)
#define DEBUG 1

// Maximum memory sequence length = 5 rows x 4 columns in the grid.
const byte MAX_MEMORY_LENGTH = 20;

// Matrix brightness (0..255)
const byte BRIGHTNESS = 4;

// Times in milliseconds
const unsigned int DISPLAY_DURATION    = 1100;  // how long the sequence is displayed
const unsigned int DISPLAY_PAUSE       = 300;   // pause after the sequence turns white
const unsigned int FEEDBACK_DURATION   = 1000;  // duration of green/red feedback
const unsigned int ROUND_PAUSE         = 600;   // pause before next round / game over screen
const unsigned int SCROLL_INTERVAL     = 70;    // scrolling text speed
const unsigned int POLL_INTERVAL       = 30;    // pause between reader checks
const byte DEBOUNCE_TIME               = 30;    // button debounce time

// --------------------------------- Pins ----------------------------------

const byte MATRIX_PIN = 5;
const byte BUTTON_PIN = 2;   // Pin 2 = interrupt 0 on UNO

const byte RESET_PIN = 9;   // shared by all 4 readers

const byte SS_PIN_1 = 10;
const byte SS_PIN_2 = 8;
const byte SS_PIN_3 = 7;
const byte SS_PIN_4 = 6;

// ----------------------------- RFID Timing -------------------------------

const byte UID_LENGTH = 4;             // UID length of chips in bytes
const byte MAX_FAILED_ATTEMPTS = 3;    // attempts before "chip removed"
const byte ANTENNA_WAIT_TIME = 5;      // wait time after antenna on (ms)

// ------------------------------ Colors -----------------------------------

const byte NUMBER_OF_COLORS = 5;

const byte COLOR_WHITE  = 0;
const byte COLOR_RED    = 1;
const byte COLOR_GREEN  = 2;
const byte COLOR_BLUE   = 3;
const byte COLOR_YELLOW = 4;

byte colors[NUMBER_OF_COLORS][3] =
{
  {255, 255, 220},  // 0 White
  {255,   0,   0},  // 1 Red
  {  0, 255,   0},  // 2 Green
  {  0,   0, 255},  // 3 Blue
  {255, 255,   0}   // 4 Yellow
};

const byte OFF[3] = { 0, 0, 0 };

// ------------------------------ Text -------------------------------------

const char START_TEXT[]    PROGMEM = "COLOR MEMORY GAME - PRESS BUTTON";
const char GAME_OVER_TEXT[] PROGMEM = "GAME OVER";

const byte CHARACTER_WIDTH = 6;   // standard font 5x7, with 6 pixel spacing
const byte TEXT_Y = 4;

// ------------------------- Chip Color Table ------------------------------
// Enter here which UID corresponds to which color.
// Stored in PROGMEM to save RAM.

struct Chip {
  byte uid[UID_LENGTH];
  byte color;             // index in colors[]
};

const Chip CHIPS[] PROGMEM = {
  // ---- Red (1) ----
  { {0x04, 0x34, 0x13, 0xBB}, 1 },
  { {0x04, 0x6A, 0x21, 0xBB}, 1 },
  { {0x04, 0x84, 0xFD, 0xBA}, 1 },
  { {0x04, 0x36, 0x13, 0xBB}, 1 },
  // ---- Green (2) ----
  { {0x04, 0x99, 0x32, 0xBB}, 2 },
  { {0x04, 0x42, 0x26, 0xBB}, 2 },
  { {0x04, 0x71, 0x21, 0xBB}, 2 },
  { {0x04, 0x53, 0x3C, 0xBB}, 2 },
  // ---- Blue (3) ----
  { {0x04, 0xD4, 0x36, 0xBB}, 3 },
  { {0x04, 0x9A, 0x3D, 0xBB}, 3 },
  { {0x04, 0x7F, 0x31, 0xBB}, 3 },
  { {0x04, 0xB1, 0x1B, 0xBB}, 3 },
  // ---- Yellow (4) ----
  { {0x04, 0x5B, 0x12, 0xBB}, 4 },
  { {0x04, 0xE6, 0x17, 0xBB}, 4 },
  { {0x04, 0x4F, 0x26, 0xBB}, 4 },
  { {0x04, 0xA6, 0x1C, 0xBB}, 4 }
};

const byte NUMBER_OF_CHIPS = sizeof(CHIPS) / sizeof(CHIPS[0]);

// ------------------------------ Objects ----------------------------------
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

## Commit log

2026-09-25 imagefiles of the schematics
2026-09-26 Updated Code, Docu, Schematic
    [PinBelegung.xlsx, mastermind.kicad_sch]
2026-09-28 added game instructions und 3d-models
    [Chipbox.stl, Layer 1 - Ground.stl, Layer 2.stl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]
2026-09-28 added seperate gain- und fieldstrength-settings and updated documentation
